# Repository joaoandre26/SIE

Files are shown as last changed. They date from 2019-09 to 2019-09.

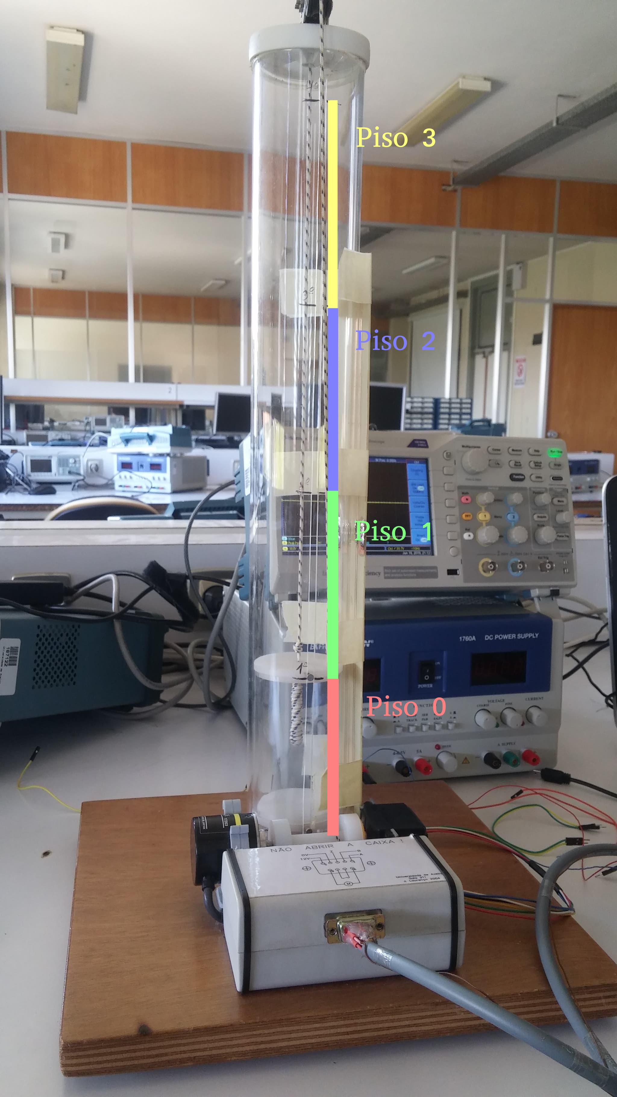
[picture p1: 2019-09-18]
Elevator_PCB/Imagens/prot_n.jpg

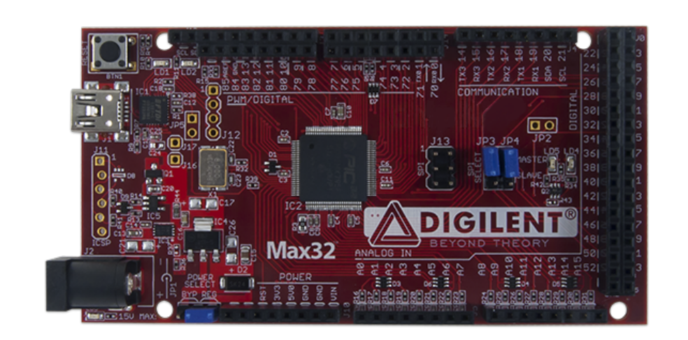
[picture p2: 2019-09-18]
Elevator_PCB/Imagens/mmicro.png

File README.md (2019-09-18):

# SIE
Trabalho desenvolvido no âmbito da UC de Sistemas de Instrumentação em Eletrónica, 4º ano MIEET, ano lectivo 2018/19
Para esclarecer alguma dúvida relativamente ao trabalho desenvolvido na UC poderá contactar um dos membros do grupo por e-mail.

/*Examples*/
Na pasta MicrocontrollerExemple-master encontra-se codigo para o qual me baseei para escrever as funções do LCD. Muito Obrigado ao desenvolvedor, foi uma grande ajuda.
Link: https://github.com/andrade824/Microcontroller-Example-Code

/*Info/Reports*/
Na pasta reports encontra-se os relatorios de todas as fases deste projecto, bem como o manual de utilizador. Deverá encontrar no manual do utilizador todas as intruções para colocar o nosso projecto em total funcionamento.

/*Elevator_PCB*/
Na pasta elevatorpcb encontra-se os gerber files para imprimir o nosso pcb, e os esquemas de montagem por nós utilizados.

/*Code*/
Na pasta Elevator_Code encontra o codigo referente ao projecto 0, assim como a versão final funcional de codigo para colocar no elevador. Existem alguns erros no codigo que poderão virificar em detalhe no report da fase 3.

Notas:
O trabalho desenvolvido que se encontra neste repositório está completamente funcional, não contemplando todas as especificações exigidas inicialmente, é o suficiente para colocar o elevador a subir e descer para qualquer um dos andares.

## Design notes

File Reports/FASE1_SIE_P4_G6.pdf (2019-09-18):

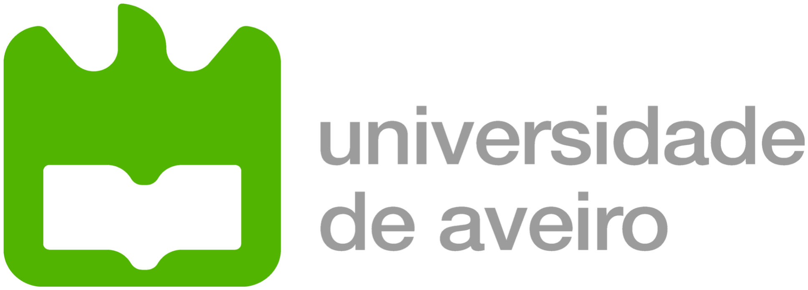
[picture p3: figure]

## Departamento de electrónica, telecomunicações e informática

Curso | 8204 - Mestrado Integrado em Engenharia Electrónica e Telecomunicações
Disciplina | 41489 - Sistemas de Instrumentação Eletrónica

## Ano Lectivo 2018/2019

# Primeira Fase

# Trabalho 4 - Controlo de Velocidade e Posição de um Elevador

## Autores:

76517 | João André de Jesus Cruz
76674 | Henrique da Silva Bernardes Camello Martins
Turma | P4
Grupo | G6
Data | 12 de Março de 2019
Docente | Pedro Fonseca

Primeira Fase - Controlo de Velocidade e Posição de um Elevador

## Índice

1 Introdução | 2
2 Objetivos | 2
3 Especificações do Projeto | 2
4 Diagramas de Blocos | 2
5 Esquema Elétrico | 5
6 Diagrama de rede - PERT | 7
7 Conclusão | 11
8 Bibliografia | 11

## 1 Introdução

Este projeto a ser realizado no contexto das aulas práticas de Sistemas de Instrumentação Eletrónica, tem como objetivo, o controlo da posição e velocidade de um elevador. Para isso, irá se desenvolver-se um sistema baseado num microcontrolador sendo este mesmo o Max32 Digilent.
Quanto ao funcionamento do elevador, resumidamente este está acoplado a um sistema cabo roldana, que está ligado a um motor e que tem o seu veio ligado a um codificador incremental bi-fásico.
A velocidade e posição do elevador, será controlada pelo microcontrolador e pelo PC. A escolha da posição será feita pelo utilizador, com recurso a uma consola. Quanto à velocidade, essa será controlada de acordo com um perfil calculado, a partir de parâmetros enviados por um PC.
Este relatório referente à primeira fase apresenta as especificações do projeto, a componente hardware, as variações e grandezas dos sinais em pontos críticos e por fim a estruturação das atividades a desenvolver.

## 2 Objetivos

Sabendo que o objetivo do projeto é o controlo e a velocidade de um elevador, este mesmo pode funcionar em duas direções diferentes (para baixo e cima), é usado um push-pull driver, que através de uma ponte H, faz com que o motor varie o sentido de rotação conforme o sinal PWN recebido.
O utilizador, como já referido na Introdução irá interagir com o sistema, podendo escolher a posição. A velocidade e a posição irá ser apresentada num display LCD.
Nesta primeira fase, tem-se como objetivos apresentar o diagrama de blocos, esquemas elétricos com o hardware detalhado, identificação dos sinais e gamas de variação, em pontos de interesse dos circuitos e no fim um diagrama PERT com a distribuição do esforço, dependências e a calendarização.

## 3 Especificações do Projeto

- Definição do ponto de chegada em coordenadas do encoder.
- Capacidade de programação dos parâmetros Vmax, Vapr e Dapr com configuração automática dos perfis
- Capacidade de alimentação de motor DC (5V / 1W).
- Encoder bi-fásico com saída TTL e 500 ipr
- Deteção de piso por sensor de proximidade (efeito de hall), com auto-calibração
- Adicionalmente: capacidade de programação dos parâmetros do controlador.
- Medição da corrente consumida.

## 4 Diagramas de Blocos

Recorrendo ao diagrama apresentado no guião dos trabalhos práticos, concluímos que como entradas temos: a posição dada pelo encoder, os quatro sensores por andar, o sensor do piso zero e o andar desejado pelo utilizador. Como saídas, temos: o controlo do motor e um display LCD para apresentar a velocidade e posição do elevador.
Posto isto, fez-se o desenho dos diagramas de blocos do nível zero ao nível dois.

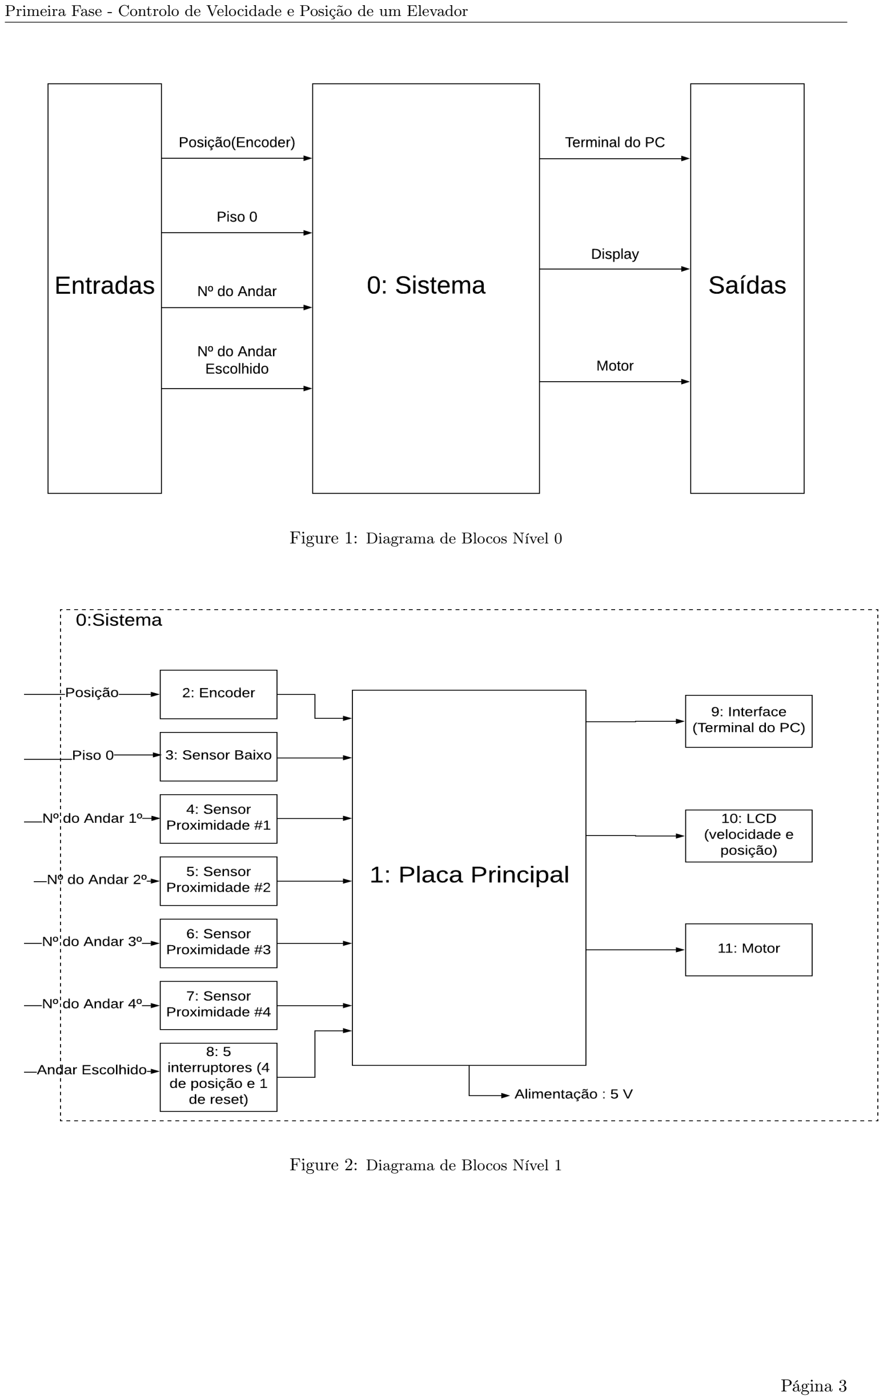
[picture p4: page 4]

Figure 1: Diagrama de Blocos Nível 0

Figure 2: Diagrama de Blocos Nível 1

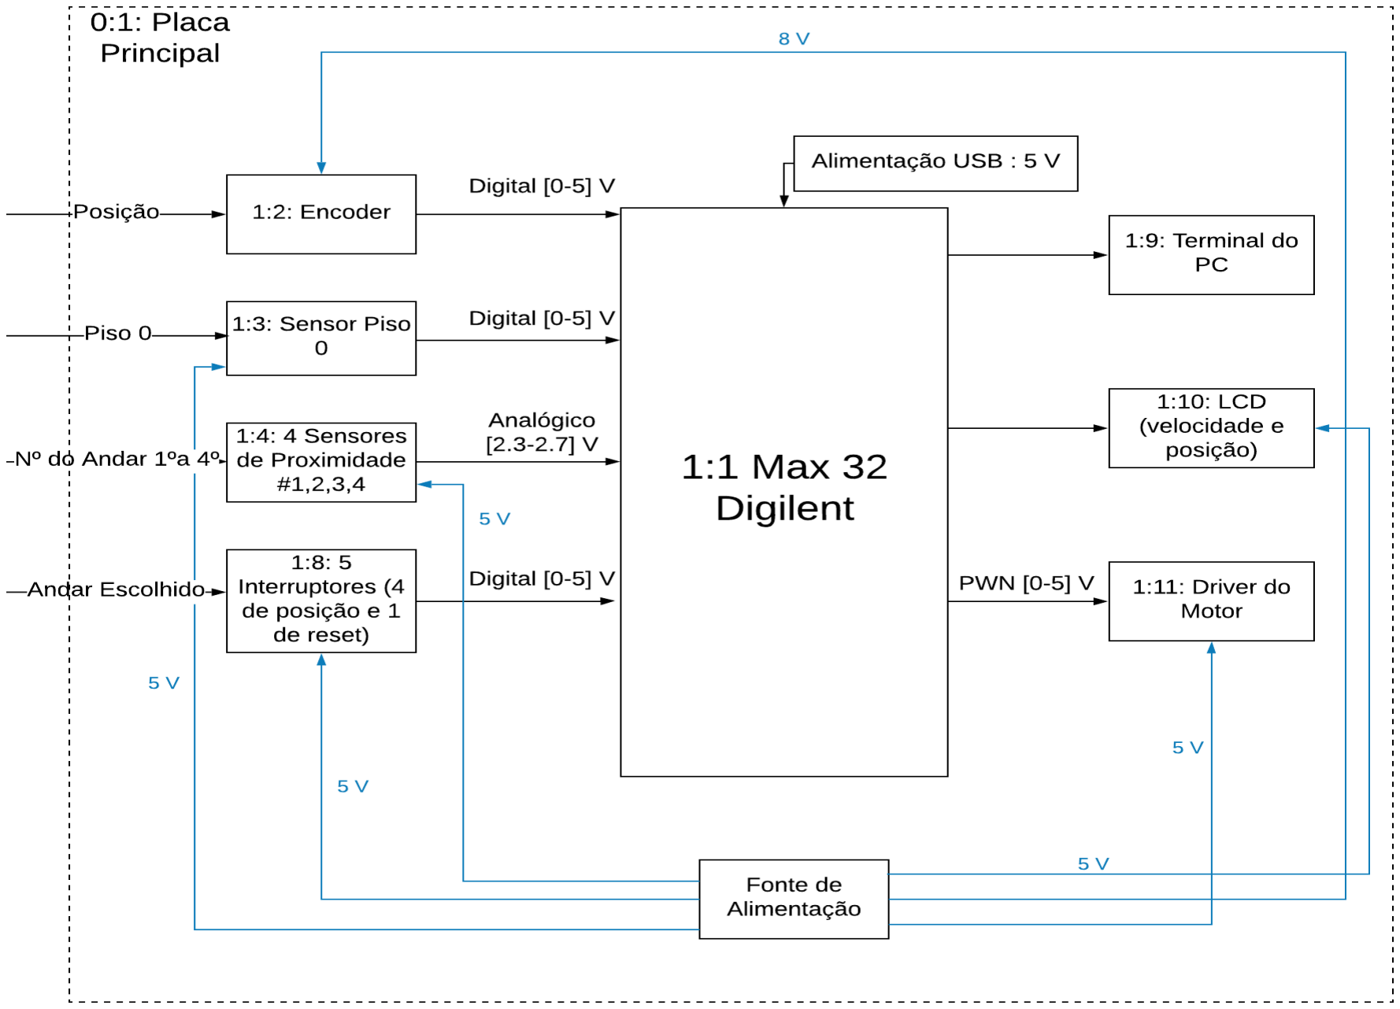
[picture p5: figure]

Figure 3: Diagrama de Blocos Nível 2

## 5 Esquema Elétrico

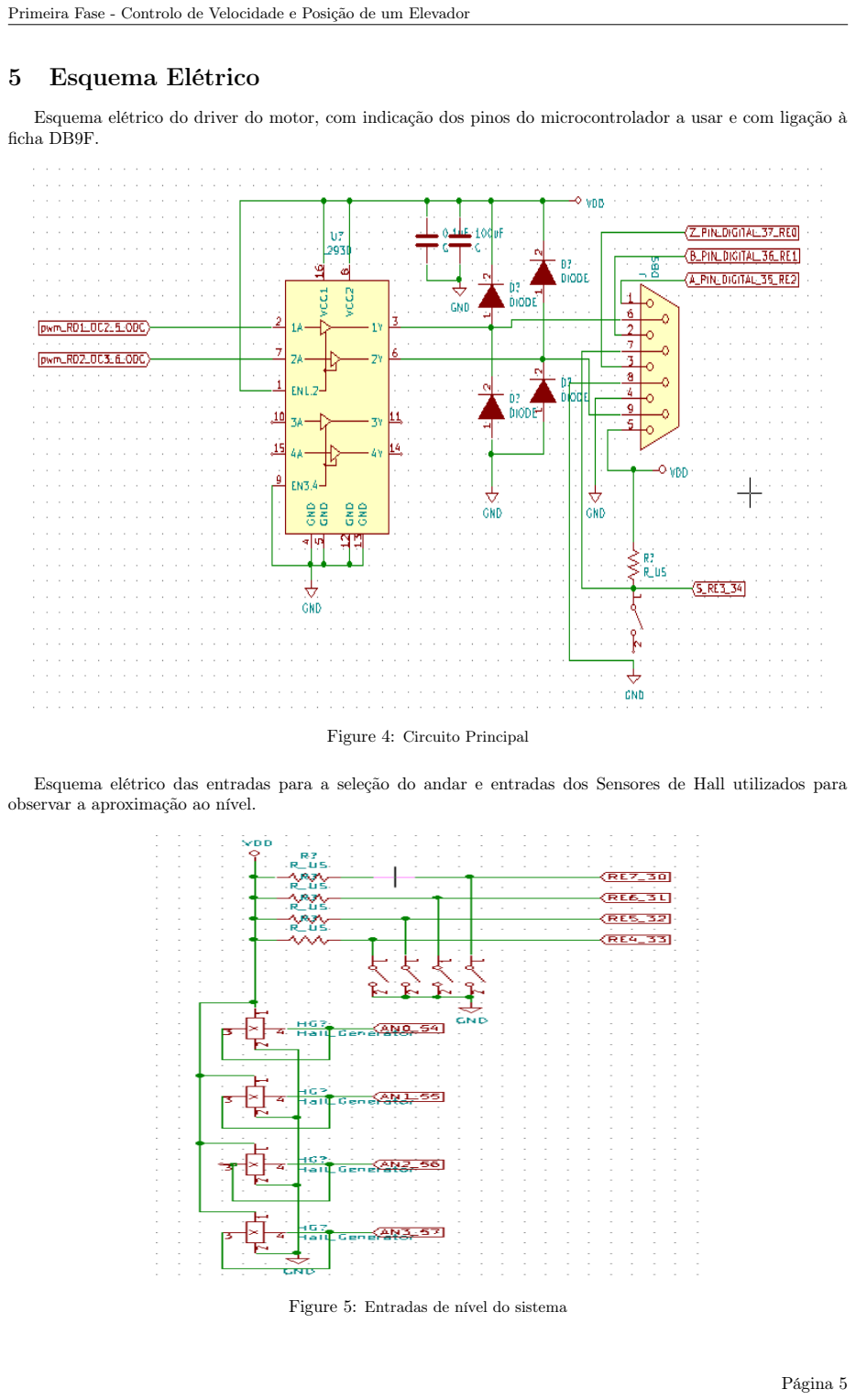
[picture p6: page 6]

Esquema elétrico do driver do motor, com indicação dos pinos do microcontrolador a usar e com ligação à ficha DB9F.

Figure 4: Circuito Principal

Esquema elétrico das entradas para a seleção do andar e entradas dos Sensores de Hall utilizados para observar a aproximação ao nível.

Figure 5: Entradas de nível do sistema

Esquema elétrico para o display da velocidade e da posição onde o elevador se encontra.

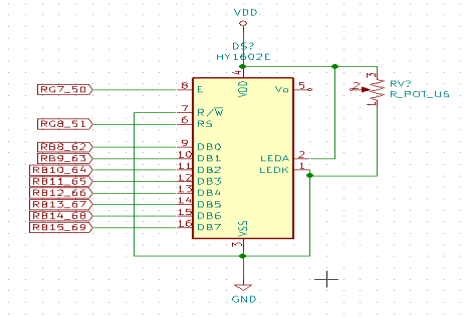
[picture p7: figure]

Figure 6: Display de resultados

## 6 Diagrama de rede - PERT

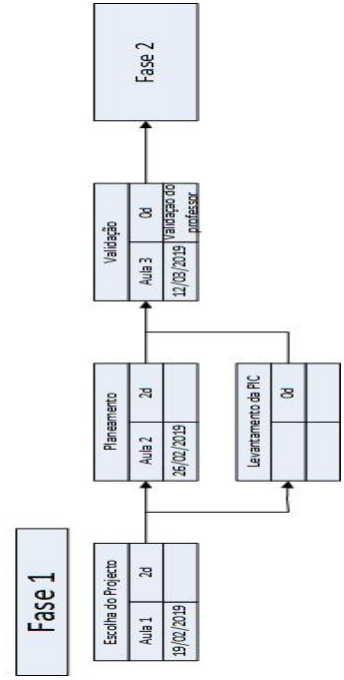
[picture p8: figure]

Figure 7: Diagrama Fase 1

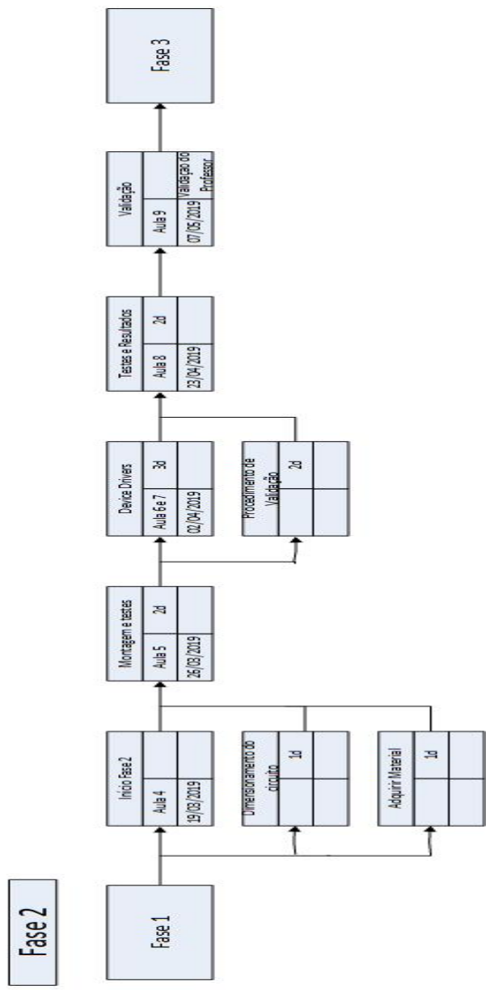
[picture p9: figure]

Figure 8: Diagrama Fase 2

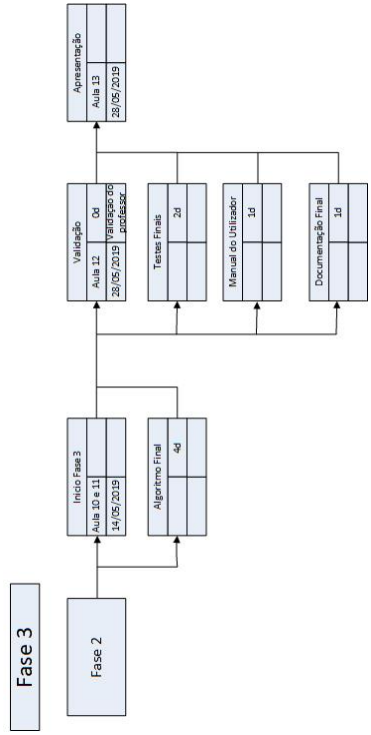
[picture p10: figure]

Figure 9: Diagrama Fase 3

1 dia = 8h de trabalho

Tabela de atividade

Atividade | Precedente | Tempo | Aula
A - Escolha | | 0d | 1
B - Planeamento | A | 2d | 2
C - Levantamento da pic | A | 0d | 2
D - Validação | B, C | 0d | 3
E - Início fase 2 | D | 0d | 4
F - Dimensionamento do circuito | D | 2d | 4
G - Adquirir Material | D | 1d | 4
H - Montagem e testes | E, F, G | 2d | 5
I - Device Drivers | H | 3d | 6 e 7
J - Procedimento de Validação | H | 2d | 6 e 7
K - Testes e Resultados | I, J | 2d | 8
L - Validação | K | 0d | 9
M - Início fase 3 | L | 0d | 10 e 11
N - Algoritmo final | L | 4d | 10 e 11
O - Validação | M, N | 0d | 12
P - Testes finais | M, N | 2d | 12
Q - Manual Utilizador | M, N | 1d | 12
R - Documentação final | M, N | 1d | 12
S - Apresentação | O, P, Q, R | 0d | 13

## 7 Conclusão

Quanto à primeira fase atingimos os objetivos impostos pelo guião da disciplina, sendo estes a apresentação dos diagramas de blocos, esquema elétrico detalhado do hardware, listagem dos tipos de sinais e gamas de variação em pontos críticos e no fim o diagrama de PERT com o planeamento do projeto.
No futuro podem haver alterações no que foi apresentado nesta fase inicial. Pois na fase seguinte, procede-se à montagem do hardware,desenvolvimento do software base e validação. As possíveis alterações serão apresen-tadas, em versões atualizadas no relatório da segunda fase.

## 8 Bibliografia

Apontamentos de Sistemas de Instrumentação Eletrónica, fornecidos pelo docente.

Esquema do Elevador,
https://elearning.ua.pt/pluginfile.php/962673/mod_resource/content/1/praticas/trabalhos/t4/elevador. pdf (https://elearning.ua.pt/pluginfile.php/962673/mod_resource/content/1/praticas/trabalhos/t4/elevador.pdf)
OMRON ,Rotary Encoder E6B2 Datasheet, https://elearning.ua.pt/pluginfile.php/962676/mod_resource/content/1/praticas/trabalhos/t4/omrom_e6b2.pdf (https://elearning.ua.pt/pluginfile.php/962676/mod_resource/content/1/praticas/trabalhos/t4/omrom_e6b2.pdf)
SGS-THOMSON MICROELECTRONICS, l293B,L293E, Datasheet, https://elearning.ua.pt/pluginfile.php/962679/mod_resource/content/1/praticas/trabalhos/t4/l293. pdf (https://elearning.ua.pt/pluginfile.php/962679/mod_resource/content/1/praticas/trabalhos/t4/l293.pdf)
HONEYWELL,SS495A-S,Datasheet https://sensing.honeywell.com/honeywell-sensing-sensors-linear-hall-effect-ics-ss490-series-\ datasheet-005843-2-en.pdf
Manual de referência online da Max32 Digilent, https://elearning.ua.pt/pluginfile.php/963675/mod_resource/content/1/chipkit-max32_rm.pdf

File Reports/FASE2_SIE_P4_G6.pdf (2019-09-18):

## Departamento de electrónica, telecomunicações e informática

Curso | 8204 - Mestrado Integrado em Engenharia Electrónica e Telecomunicações
Disciplina | 41489 - Sistemas de Instrumentação Eletrónica

## Ano Lectivo 2018/2019

# Segunda Fase

# Trabalho 4 - Controlo de Velocidade e Posição de um Elevador

## Autores:

76517 | João André de Jesus Cruz
76674 | Henrique da Silva Bernardes Camello Martins
Turma | P4
Grupo | G6
Data | 7 de Maio de 2019
Docente | Pedro Fonseca

Segunda Fase - Controlo de Velocidade e Posição de um Elevador

## Índice

1 Introdução | 2
2 Objetivos | 2
3 Especificações do Projeto | 2
4 Descrição do Hardware | 3
5 Arquitetura de Software | 9
6 Testes e Resultados | 14
7 Memória Descritiva | 27
8 Conclusão | 28
9 Bibliografia | 28

## 1 Introdução

Este projeto a ser realizado no contexto das aulas práticas de Sistemas de Instrumentação Eletrónica, tem como objetivo, o controlo da posição e velocidade de um elevador. Para isso, irá se desenvolver-se um sistema baseado num microcontrolador sendo este mesmo o Max32 Digilent.
Quanto ao funcionamento do elevador, resumidamente este está acoplado a um sistema cabo roldana, que está ligado a um motor e que tem o seu veio ligado a um codificador incremental bi-fásico.
A velocidade e posição do elevador, será controlada pelo microcontrolador e pelo PC. A escolha da posição será feita pelo utilizador, com recurso a uma consola. Quanto à velocidade, essa será controlada de acordo com um perfil calculado, a partir de parâmetros enviados por um PC.
Este relatório referente à segunda fase apresenta as especificações dos procedimentos de validação e várias tabelas com os resultados dos testes efetuados. É importante referir que no fim da segunda fase todos os componentes estão montados e o software base está desenvolvido.

## 2 Objetivos

Sabendo que o objetivo do projeto é o controlo e a velocidade de um elevador, este mesmo pode funcionar em duas direções diferentes (para baixo e cima), é usada uma ponte H que faz com que o motor varie o sentido de rotação conforme o sinal PWN recebido.
O utilizador, como já referido na Introdução irá interagir com o sistema, podendo escolher a posição. A velocidade e a posição irá ser apresentada num display LCD.
Na segunda fase, tem-se como objetivos a apresentação das especificações dos procedimentos de validação, várias tabelas com os resultados dos testes efetuados, todos os componentes devidamente montados e o software base desenvolvido.

## 3 Especificações do Projeto

- Definição do ponto de chegada em coordenadas do encoder.
- Capacidade de programação dos parâmetros Vmax, Vapr e Dapr com configuração automática dos perfis
- Capacidade de alimentação de motor DC (5V / 1W).
- Encoder bi-fásico com saída TTL e 500 ipr
- Deteção de piso por sensor de proximidade (efeito de hall), com auto-calibração
- Adicionalmente: capacidade de programação dos parâmetros do controlador.
- Medição da corrente consumida.

## 4 Descrição do Hardware

### 4.1 Driver do Motor

Para o driver do motor utilizou-se o integrado L293NE. Após a análise do datasheet do componente e da investigação do funcionamento de uma Ponte H chegámos às seguintes conclusões.
O L293 é controlado por um sinal PWM, que terá de ter uma tensão mínima de alimentação e lógica de cerca de 4.5 V. Posto isto, recorremos às saídas open drain do micro controlador que permitem a geração de sinais até 5 V, o que cumpre com os mínimos de tensão anteriormente apresentados. A alimentação do componente, é feita através da fonte de alimentação da bancada da sala de aula.
Quanto ao funcionamento da ponte H este é um circuito que contém normalmente quatro transístores bipolares FETs que funcionam como switches. Cada um é controlado individualmente. Com Q1 e Q4 ativos há passagem de corrente pelo motor fazendo com que rode num sentido. Com Q3 e Q2 ativos o motor roda no sentido contrário. Os quatro transístores nunca podem estar os quatro ativos pois pode-se danificar o circuito. No caso do L293 já possui um mecanismo de proteção para este tipo de situação.
O controlo do L293 é feito com um sinal PWM que corresponde a um sinal periódico retangular com frequência constante em que o seu tempo ON (sinal a 1) pode ser variável. Para isso varia-se o duty cycle que equivale à relação do período do sinal e o período a ON (sinal a 1). Logicamente com a variação do duty cycle do sinal PWM consegue-se controlar, o tempo em que os transístores estão ativos, o que equivale a controlar a velocidade do motor. A expressão do duty cycle do sinal PWM é dado pela seguinte fórmula:

DutyCycle =

tON
T

∗ 100%

Já as conexões entre o motor e o driver são efetuadas através de uma ficha DBF9, que está no elevador, foi então necessário um cabo com uma ficha num dos lados e headers na outra, para fazer a ligação necessária. Tal como é visível no seguinte esquema:

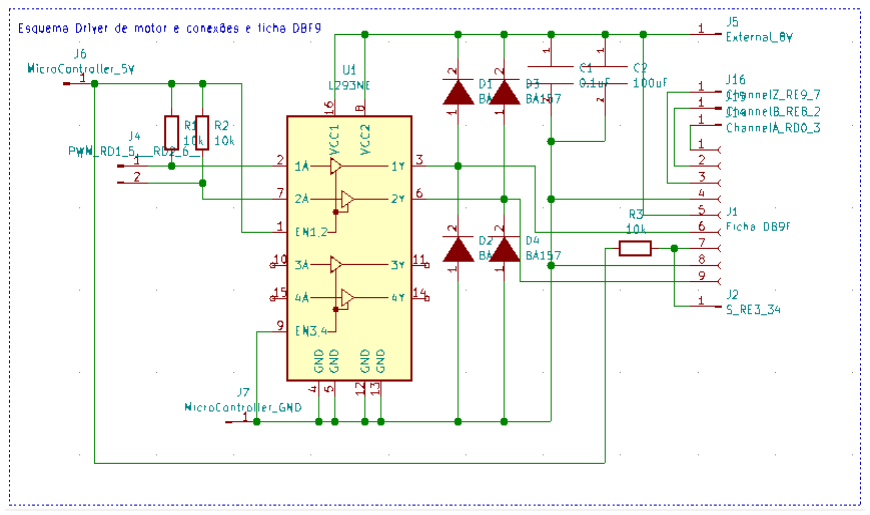
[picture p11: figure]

Figure 1: Esquema Elétrico do driver de motor

Os pinos utilizados nos quais obtemos um sinal PWM como saída, correspondem aos pinos 5 (RD1) e 6 (RD2) do Kit, o ground e a alimentação, que contém uma resistência de pull-up para cada uma das saídas de PWM, para que o open drain funcione.

### 4.2 Interface com o utilizador

### 4.3 Display LCD

Para a apresentação da posição e da velocidade do elevador escolheu-se usar um display LCD.
O display LCD tem como pinos: o display de contraste (V0), pinos de alimnetação (5V e GND), 8 pinos de dados (D0-D7), um pino do modo de leitura ou escrita (R/W), um pino de enable para autorizar a escrita nos registos e por fim um pino da escolha do registo(RS) que controla onde se escreve na memória do LCD ou enviar comandos.
O display LCD pode ser controlado por dois modos de 4 bits e de 8 bits. O de 4 bits requer o uso de sete pinos do microcontrolador e o de 8 bits o uso de 11 pinos.
Na figura seguinte apresenta-se o esquema elétrico com as ligações do display LCD.

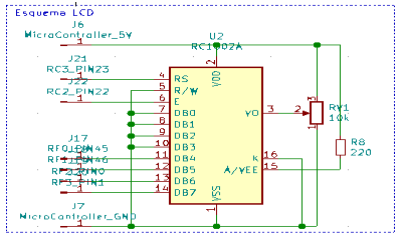
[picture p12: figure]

Figure 2: Esquema Elétrico do LCD

Para ligar o LCD à PIC utilizamos o modo de 4 bits e os pinos RS e E, não é necessário ligar o pino R/W uma vez que apenas se vão efectuar operações de escrita, assim este pino so precisa de ser ligado à massa. Os 4 pinos de dados (DB4-DB7) foram ligados aos pinos 45 (RF0), 46 (RF1), 0 (RF2) e 25 (RF3), já o pino enable ao 22 (RC2) e o pino RS ao 23 (RC3).

### 4.4 Botões

Para o controlo da posição do elevador utilizaram-se quatros botões, um para cada piso.
Na figura seguinte apresenta-se um esquema sintético de um push button, quando o botão é acionado cria-se uma ligação entres os pinos de cada lado (BC e AD) onde neste caso ocorre passagem de corrente.

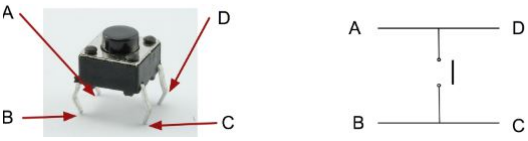
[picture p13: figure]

Figure 3: Esquema Elétrico de um push button

Quando à montagem dos botões recorreu-se a uma tensão de alimentação de 5 V (5 V do porto do microcontrolador),conectou-se uma resistência de pull up de cerca de 10kΩ em série com o botão (uma em cada botão) e por fim liga-se um pino do microcontrolador entre a resistência e o botão para assim fazer-se a sua leitura. Posto isto, a resistência liga-se ao pino B do botão e o pino D liga-se à massa. Na figura seguinte apresenta-se as ligações feitas dos quatro botões.
Pretende-se que o botão apresente apenas dois estados High(5 V) e Low (0 V) para isso é que se usou a resistência pull up com o objetivo que o valor não varie. Quando o botão não está premido, o circuito está em aberto fazendo com que a queda de tensão na resistência seja nula, logo o valor de tensão lido pelo microcontrolador é de 5 V equivalente ao estado High, mais tarde negado pelo software. No caso de estar premido, o circuito encontra-se fechado logo ocorre passagem de corrente no botão e por consequência a queda de tensão na resistência é de cerca de 5 V. Portanto o valor de tensão lido pelo microcontrolador é de 0 V equivalente ao estado Low, sendo que mais tarde é negado pelo software. Assim o microcontrolador consegue fazer uma leitura correta do estado do botão em causa e concluir se o botão está premido ou não.
Tal como já está descrito acima a forma como os push butons funcionam, mostra-se na figura seguinte como se conectam ao microcontrolador.

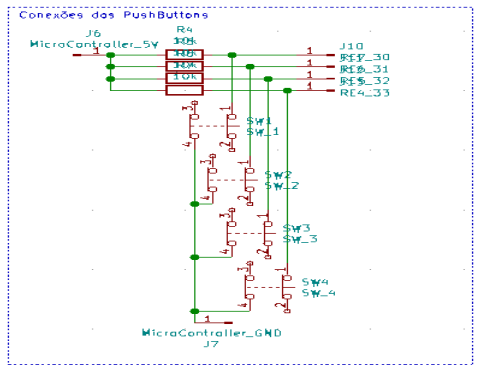
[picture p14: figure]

Figure 4: Esquema Elétrico dos PushButtons

Como é visível no esquema eléctrico os quatro botões encontram-se ligados aos pinos 30 (RE7), 31 (RE6), 32 (RE5) e 33 (RE4), enquanto o botão do piso zero se encontra ligado ao pino 34(RE3).

### 4.5 Encoder

Neste projeto usa-se um encoder incremental que produz 500 impulsos por revolução e tem três canais A,B e Z. O modelo usado neste projeto é o E6B2-CWZ6C da OMRON.
O encoder tem dois sentidos de rotação, sentido horário ou anti-horário. Analisando o sentido horário, a fase A irá estar adiantada 90º em relação à fase B. Comparando diretamente a fase A e B e observando atentamente o nível das duas fases, chega-se à conclusão que neste caso (sentido horário) o nível da fase A é diferente do da fase B. Logo quando há uma mudança do nível da fase A o nível da fase B contraria o nível do da A. Este fenómeno é evidenciado na figura seguinte.
No sentido anti-horário a fase A encontra-se atrasada 90º em relação à fase B. Quanto ao nível das fases, neste caso, encontram-se sempre iguais. Este fenómeno é evidenciado na figura seguinte. Portanto através da leitura e análise das fases do encoder, consegue-se afirmar qual o sentido de rotação deste mesmo, recorrendo a um algoritmo simples de controlo por software. Este baseia-se na observação do nível das fases, quando o nível do canal B é diferente do A incrementa-se a posição pois o encoder roda no sentido horário. Com os níveis dos dois canais diferentes a posição decrementa-se pois roda no sentido anti-horário.

(a) Fases A,B e Z | (b) Níveis das fases A,B e Z

Figure 5: Sentido horário

(a) Fases A,B e Z | (b) Níveis das fases A,B e Z

Figure 6: Sentido anti-horário

Quanto à implementação, sabe-se que a porta DB9F tem os três canais e que cada um é um sinal TTL de 5V. Logo pode-se ligar diretamente as fases ao microcontrolador, pois os pinos deste mesmo são tolerantes a 5V. A leitura dos níveis dos três canais é feito com interrupções externas que detetam mudanças de nível, sabendo que apenas alguns dos pinos são tolerantes a interrupções deste género, selecionaram-se as interrupções 0, 1 e 2, que correspondem aos pinos 3(RD0), 2(RE8) e 7(RE9) para as fases A, B e Z,respetivamente. O método implementado está mais à frente aprofundado na secção Arquitetura de Software.
Quanto à alimentação do encoder, de acordo com o seu datasheet, é cerca de 5 V. Aplica-se uma tensão à fonte de alimentação do elevador, que por sua vez alimenta o elevador mais o encoder. Este regulador é o tipo 7805 que pelo seu datasheet necessita no mínimo 7V de tensão de alimentação para funcionar corretamente. E ainda existe um díodo que apresenta uma queda de tensão, logo considerando todos estes fatores mais o conselho por parte do docente, a alimentação irá ser de 8V.

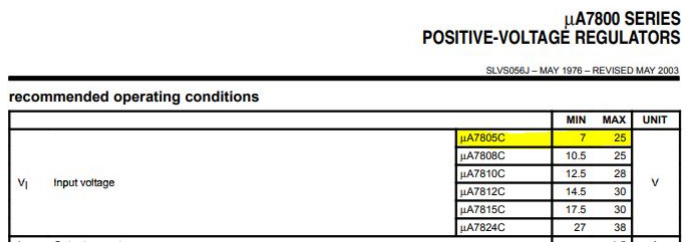
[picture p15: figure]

Figure 7: Extrato do Datasheet do LM7085

### 4.6 Sensor de Efeito de Hall

O efeito de Hall por definição é: o aparecimento de uma diferença de potencial em um condutor elétrico, transversal ao fluxo de corrente e um campo magnético perpendicular à corrente.
Os Sensores de efeito de Hall são ativados por um campo magnético exterior, logo o sinal de saída é em função da densidade do campo magnético na proximidade do sensor. O campo magnético tem dois aspetos a densidade de fluxo magnético (B) e a sua polaridade (Norte ou Sul). No caso do sensor ser linear e for analógico, a sua tensão de saída é dada pela equação seguinte:

Vth = Rth ∗ (

I
t

∗ B)

Em que Vth é a tensão de Hall, Rth é o coeficiente de Hall, I é a corrente que atravessa o sensor, t é a espessura do sensor em (mm) e B é o fluxo magnético em Tesla. A resposta típica de um sensor de Hall a um campo magnético é dado pelo seguinte gráfico. Conclui-se que a tensão de saída do sensor aumenta com o aumento do campo magnético, até que comece a saturar pelos limites impostos pela sua alimentação. Portanto vê-se que a tensão de saída é proporcional ao campo magnético.

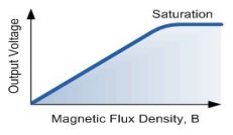
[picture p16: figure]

Figure 8: Gráfico V0/B num sensor de efeito de Hall

Quanto ao projeto em si, cada andar possui um sensor, obtendo no total quatro sensores de efeito de Hall de modelo SS495A da Honeywell. Após uma leitura e análise do datasheet do componente, conclui-se que para uma densidade do campo magnético de 0 B apresenta uma tensão de saída referencia de 2.5 V (Vdc). Com um campo magnético aplicado (de -670 B a 670 B tipicamente) obtêm-se variações típicas de 0.2 ∗ Vdc a Vs − (0.2 ∗ Vdc), também se sabe que a tensão de alimentação tem de ser no mínimo 4.5 V. Portanto sabendo que os pinos do microcontrolador conseguem produzir uma tensão de 5 V, os sensores são alimentados com ela e obtém-se uma variação entre 0.5 V e 4.5 V à saída de cada um. Este facto pode-se observar no gráfico seguinte do datasheet do componente.

(a) Gama da tensão de saída
(b) Gama da densidade do campo magnético
(c) Gráfico V0/B

Figure 9: Extratos do Datasheet do SS495A

A montagem dos sensores de Hall já se encontra feita no elevador logo, apenas é necessário fazer a leitura de cada sensor recorrendo ao microcontrolador e fazer a sua devia alimentação. Para se lerem os valores de tensão obtidos nos sensores é necessário utilizar uma ADC, em que a mesma seja uma porta analógica, neste caso em concreto usou-se as portas analógicas AN0, AN1, AN2 e AN3 que correspondem aos pinos 54(RB0) a 57(RB3). Mais à frente na secção dos testes, conclui-se que o sensor na presença de um campo magnético tem uma tensão de saída de cerca de 2.4V, com um tensão referencia de 2.5V.

Figure 10: Esquema da montagem dos sensores de efeito de Hall

## 5 Arquitetura de Software

Nesta secção do relatório da fase dois, são apresentados os device drivers e fluxogramas que ajudam a compreender o seu funcionamento.
Para a melhor organização, foi criado um ficheiro para cada módulo desenvolvido. Logo tem-se que :

PWM

LCD

ADC

Encoder

PushButtons

UART

É importante frisar que poderão ocorrer alterações dos device drivers na ultima fase do projeto mas na altura serão devidamente evidenciadas.

### 5.1 ConfigBits

Este módulo já nos é fornecido, tem como função a configuração do CLOCK e PBCLK, com os valores 80MHz e 40MHz, respetivamente.

### 5.2 PWM

Este módulo, junta todas as funções necessárias, para gerar dois sinais PWM com duty cycle variável e frequência de 20kHz. A figura seguinte resume o funcionamento do módulo desenvolvido.

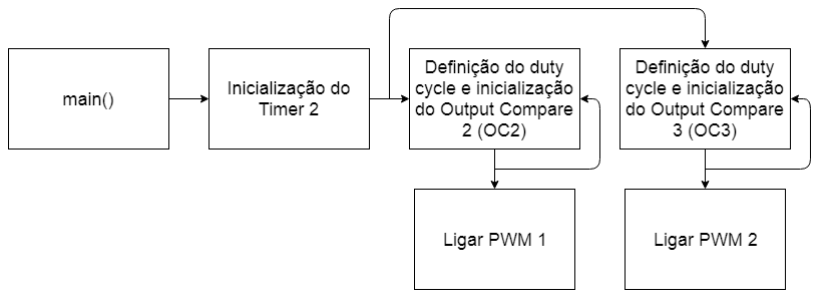
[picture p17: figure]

Figure 11: Diagrama de Fluxo da geração de duas PWM

A configuração deste módulo em específico foi facilitado pelo código já desenvolvido no projeto 0. Para a geração dos dois sinais PWM foi usado o Output Compare (OC2 e OC3) e para ambos o Timer 2 com uma frequência de cerca de 20kHz.
As funções desenvolvidas foram as seguintes:

SetTimer(void)

SetPWN1(dutyCycle)

SetPWN2(dutyCycle)

StartTimer(void)

A função SetTimer inicia os portos e configura o Timer 2 com uma frequência de 20 kHz. Para esse efeito usa-se a expressão enuncia a seguir para se obter o valor do PR2. Sendo o fin = 40MHz e o valor pretendido para a frequência fout = 20k o valor obtido para o PR2 é de 2000, com um valor de prescaler de 1.

fout =

fin
P Rx + 1

A função SetPWM1 e SetPWM2, são equivalentes sendo que, ambas têm como parâmetro de entrada o valor de duty cycle desejado pelo utilizador e cada uma produz um sinal PWM. A primeira recorre ao Output Compare 2 e a segunda ao Output Compare 3, ambas como já referido anteriormente usam o Timer 2. A partir do registo OC2RS e OC3RS respetivamente, é possível alterar os valores dos duty cycles dos sinais PWM’s gerados, de acordo com a seguinte formula:

OCxRs =

(P R2 + 1) ∗ δ
100

O sinal PWM proveniente do SetPWM1 é obtido no pino 5 e o do SetPWM2 no pino 6 da. Para além disto foram configuradas as saídas em open drain para que se consigam gerar sinais PWM com tensão máxima de 5V. Pois a ponte H necessita de tensões mínimas de 4.5 V, desta maneira evita-se o uso de hardware adicional, o que é uma vantagem. Apenas se usa um pull up resistor por cada saída.
Por fim a função StartTimer inicia a geração dos dois sinais PWM, configurando o registo T2CONbits.TON a 1.

### 5.3 LCD

Este módulo é responsável pelo display do da velocidade e o nível onde o elevador se encontra. A figura seguinte resume o funcionamento do módulo desenvolvido.

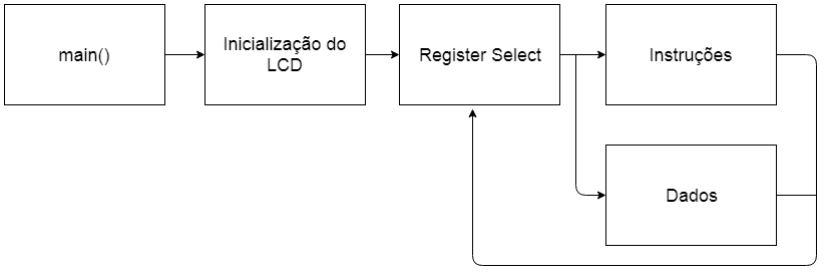
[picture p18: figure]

Figure 12: Diagrama de Fluxo da impressão de informação no LCD

Para a configuração e o display, o envio de comandos e caracteres, foram criadas as seguintes funções:

InitialiseDisplay(void)

ResetDisplay(void)

SendCommandToLCD(uint8_t uiCommand)

LCDSendString(char * str)

LCDSendChar(char character)

delay(uint32_t period)

A função mais importante deste módulo é a SendCommandToLCD, esta função é responsável por enviar comandos com as tarefas que o display deve executar, como Clear, Return Homne, Mode Set, Display ON/OFF, cursor Shift, etc. Estes comandos são responsáveis por muitos das tarefas que o display executa.
Depois da funçao anterior a função mais importante é InitialiseDisplay, esta função executa alguns dos comandos pela função anterior, que são responsáveis pelo iniciar do display, como o modo de funcionamento, 4/8bits ou 1/2 linhas, desligar o cursor, iniciar o Entry Mode seguindo-se pelo inicial do display. Entre cada um dos comandos é necessário um delay para que o comando seja executado, para isso existe também uma simples função que cria um delay, como parâmetro de entrada o valor de delay que se pretende em mS.
A função ResetDisplay executa por algumas vezes o Return Home.
Por fim as funções LCDSendString recebe um ponteiro de caracteres e envia um de cada vez para ser enviado para a função LCDSendChar, esta última envia os caracteres para o LCD.

### 5.4 ADC

Este módulo, junta todas as funções necessárias, para realizar a leitura da tensão dos quatro sensores de Hall. A figura seguinte resume o funcionamento do módulo desenvolvido.

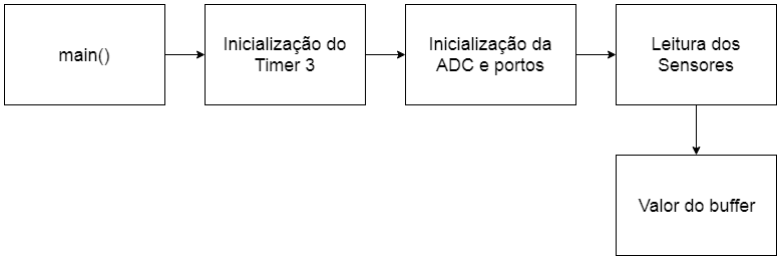
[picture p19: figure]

Figure 13: Diagrama de Fluxo da leitura dos sensores de Hall

As funções desenvolvidas foram as seguintes:

initADC(void)

initADCTimer(void)

readADCx(void)

buffer(void)

A primeira função deste módulo é initADC, esta função é responsável pelas configurações da ADC e a iniciação dos portos analógicos desta. São configurados os portos AN0 a AN3 como entradas.
A função initADCTimer serve para que seja feita uma leitura ao buffer com uma determinada frequência de amostragem sendo esta de cerca 400Hz. Para isso usou-se o Timer 3 com valores de prescaler e PR3, de 2 e 50000.
As funções readADCx, são 4 uma para cada sensor, cada uma seleciona o porto analógico devido a ler e fazem a decisão da comparência do elevador no andar em questão.
A função buffer é usada apenas para devolver o valor do buffer lido da ADC.

### 5.5 Encoder

Este módulo é responsável pela leitura dos três canais do encoder e pela decisão do sentido do movimento de elevador (para cima ou para baixo). A figura seguinte resume o funcionamento do módulo desenvolvido.

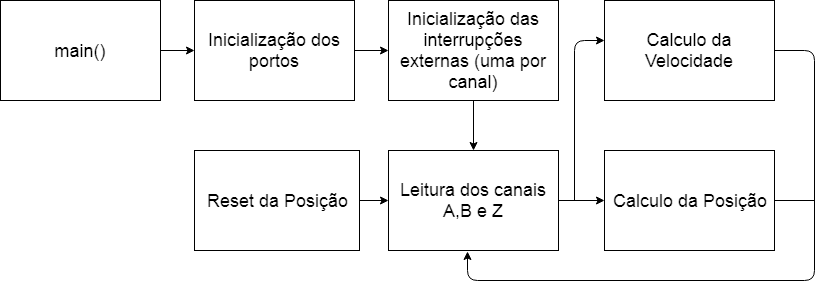
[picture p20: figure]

Figure 14: Diagrama de Fluxo da leitura dos canais A,B e Z, mais calculo de posição e velocidade

As funções implementadas neste módulo são as seguintes:

SetEncoderPorts(void)

SetExternalIntx(void)

GetChannelx(void)

GetPos(void)

ResetPos(void)

Init_Timerx_Interrupt()

A função SetEncoderPorts, serve para definir os portos de entrada responsáveis pela leitura do estado dos canais do encoder (Canal A,B e Z)
A SetExternalIntx inicia as interrupções externas para cada um dos canais A,B e Z do encoder.
A GetChannelx é responsável pela leitura do estado dos canais.
A função GetPos e ResetPos são responsáveis por devolver a posição do encoder e colocar o mesmo valor a zero.
Já a última função Init_Timerx_Interrupt, inicia dois timers por interrupções, cada um deles responsável pelo update da posição e o outro por calcular a velocidade. Tem-se o Timer 4 com uma frequência de 50Hz sendo este responsável pela obtenção da posição do elevador e o Timer 1 com uma frequência de 400Hz para o calculo da velocidade. O calculo da posição é feito por um método muito usado por software. Este algoritmo compara o estado dos canais A e B, se forem diferentes incrementa-se o contador da posição e forem iguais decrementa-se. O da velocidade faz-se a amostragem com uma frequência de 400Hz e dentro desse espaço de tempo vê-se a variação da posição do elevador. No fim divide-se a variação de posição pelo periodo de amostragem.
Sendo o objetivo deste módulo a leitura dos três canais do encoder, as funções SetExternalIntx estão configuradas para serem ativas numa raising edge do porto e no momento em que corre a interrupção lê-se o estado do canal e inverte-se o seu funcionamento para failing edge. Isto é possível graças ao registo INTCONbits.INTxEP. Logo com este principio de funcionamento o microcontrolador consegue ler com sucesso os três canais do encoder.

### 5.6 PushButtons

Este módulo é responsável pela leitura do estado dos quatro botões e do bottom switch instalado no elevador. A figura seguinte resume o funcionamento do módulo desenvolvido.

Figure 15: Diagrama de Fluxo da leitura dos botões e do bottom switch

Para isso criaram-se as seguintes funções:

InitButtons(void)

PushButtonx(void)

BottomSwitch(void)

A função InitButtons é responsável pela configuração das portas RE3 a RE7 como entradas.
Já as funções PushButtonx são as responsáveis por retornar o estado dos botões, 1 a 4 e do bottom switch. Estes mesmos estão ligados às porta RE3 a RE7.

### 5.7 UART

Este modulo surge da necessidade do sistema comunicar com o utilizador. A figura seguinte resume o funcionamento do módulo desenvolvido.

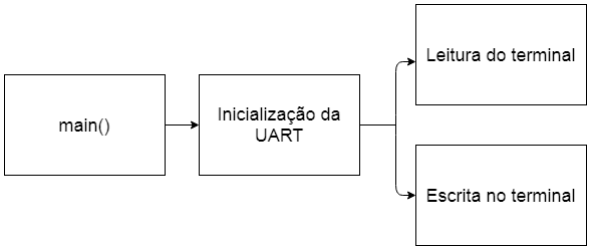
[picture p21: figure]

Figure 16: Diagrama de Fluxo da utilização da UART

Para tal foram usadas as funções seguintes:

InitUART(void)

PutChar(char r)

PutString(char *str)

GetChar(void)

A primeira função, InitUART, é responsável pela configuração da UART. Para isso é necessário definir a baudrate por forma a calcular o Baud Rate Register, por fim é necessário apenas iniciar a transmissão e a recepção. Para calcular o valor do registo mencionado utiliza-se a seguinte expressão:

UxBRG =

P BCLK + 8 ∗ baudrate
1616 ∗ baudrate − 1

As restantes funções PutChar, PutString e GetChar, estas são responsáveis pelo envio e receção de caracteres na uart. A primeira pela escrita do caracter como argumento, a segunda pela escrita de uma string no formato de array de caracteres e a terceira para a leitura de caracteres do terminal.

## 6 Testes e Resultados

### 6.1 Testes da geração dos sinais PWM

Objetivo:

Este teste tem como objetivo verificar a geração de dois sinais PWM, com tensão pico a pico de 5V, para um dado valor de duty cycle com uma frequência de 20 KHz.

Descrição e Resultados Esperados:

Tendo em conta que a ponte H, necessita de uma tensão mínima de 4.5 V, as saídas da Max32 Digilent têm de estar configuradas em open drain, pois com esta configuração consegue-se gerar sinais PWM de 5 V. Apenas se tem de adicionar um pull up resistor ao pino de saída.
Utilizando as funções StartTimer, SetPWM1 e SetPWM2, gerou-se na PWM1 um sinal com duty cycle de 50 % e na PWN2 com 30 %.
É expectável observar dois sinais PWM com os duty cycles referidos anteriormente e com uma tensão pico a pico de cerca de 5V.

Resultados:

Recorrendo ao osciloscópio da bancada mediram-se os dois sinais PWM gerados, tendo obtido as três figuras seguintes. Na primeira têm-se o sinal PMW1 com duty cycle de 50 %, na segunda a PWM2 com dutycycle de 30 e por fim os dois sinais juntos.

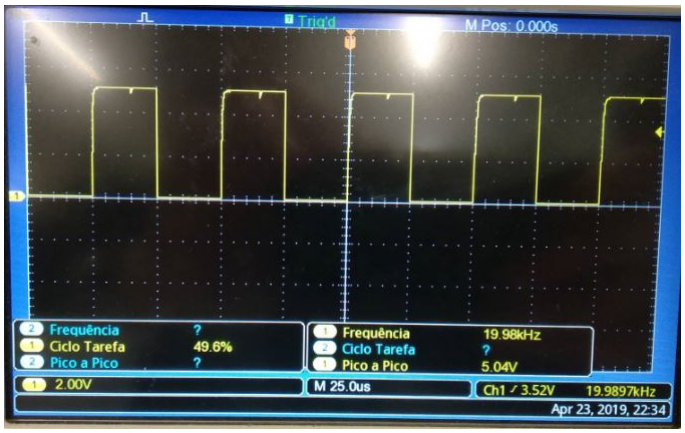
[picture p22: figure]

Figure 17: PWN 1 com δ = 50%

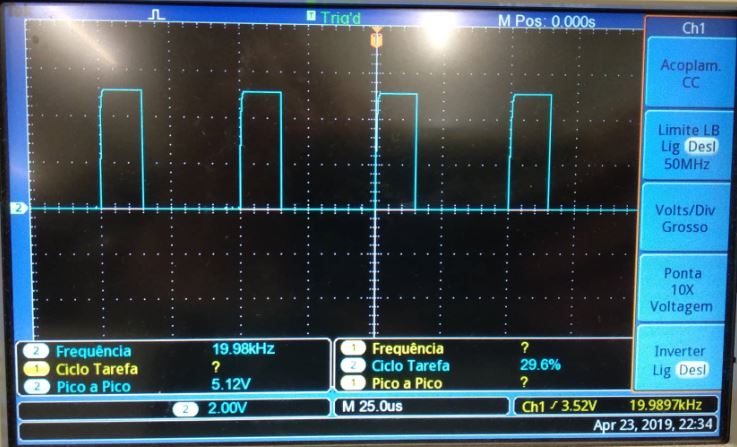
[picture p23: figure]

Figure 18: PWN 2 com δ = 30%

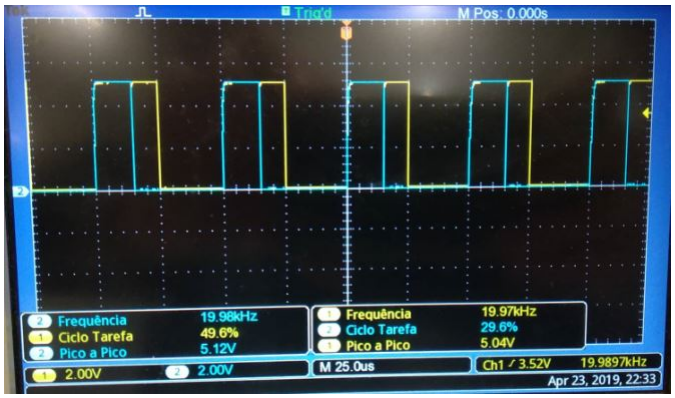
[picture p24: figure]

Figure 19: PWM 1 com δ = 50% e PWM 2 com δ = 30%

Análise:

Os valores de duty cycle obtidos vão de encontro com o esperado. Quanto à frequência de ambas é cerca de 20kHZ e tensão máxima de 5 V como esperado. Portanto conclui-se que os resultados obtidos vão de encontro ao expetável e estão corretos. Sendo que este módulo é capaz de produzir dois sinais PWM à escolha, com qualquer valor de duty cycle e frequencia de 20kHz.

### 6.2 Testes dos sinais obtidos na ponte H e movimento do elevador

Objetivo:

Verificação do bom funcionamento da ponte H e observação do movimento do elevador.

Descrição e Resultados Esperados:

Com vista em testar a ponte H, foi montada de acordo com o já explicado na secção Arquitetura de Software
- Driver do Motor.

Utilizando as funções StartTimer, SetPWM1 e SetPWM2 geraram-se dois sinais PWM para várias combinações de duty cycles. Os pares de valores foram 70% e 0% , 0% e 70%, 100% e 0%, 0% e 100% e por fim 50% e 50%.
Quanto aos resultados expectáveis, no primeiro par de valores um sinal PWM com visto anteriormente em Testes da geração dos sinais PWM - Resultados para o PWM 1 e no PWM2 uma tensão de cerca de 0V. No segundo par de valores o inverso da situação anterior, no terceiro na PWM1 uma tensão constante de 5V e na PWM2 uma tensão de cerca de 0V, no quarto o inverso dos resultados na terceira e por ultimo dois sinais PWM exatamente iguais.
Quanto ao movimento do elevador se o duty cycle da PWM1 é maior que a PWM2 o elevador desce, inversamente se o duty cycle da PWM2 for maior que o da PWM1 o elevador sobe. No caso em que os sinais são iguais o elevador prevê-se não possuir qualquer movimento. Também se prevê que quanto maior o dutycyle da função mais rápido será o deslocamento do elevador, pois maior é o tempo em que o sinal se encontra a ON.

Resultados:

Utilizando as funções já enunciadas na secção Testes e Resultados - Testes de geração dos sinais PWM e usando vários valores de duty cycle para cada um dos sinais PWM, estes dois sinais foram conectados às entradas na Ponte H. Logo utilizando o osciloscópio da bancada, as saídas da ponte H foram as seguintes:

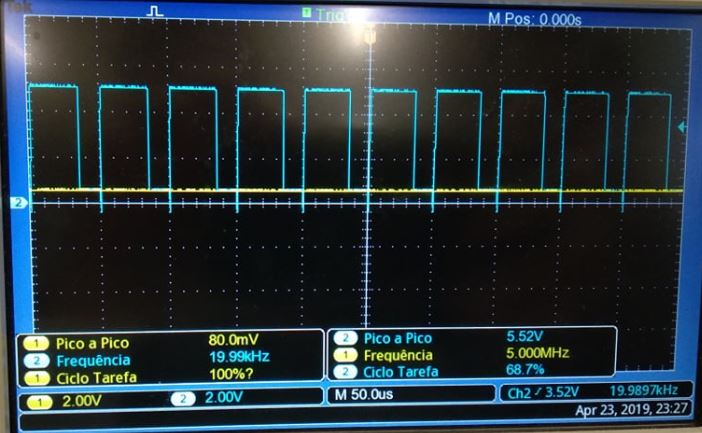
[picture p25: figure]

Figure 20: PWM 1 com δ = 70% e PWM 2 com δ = 0%

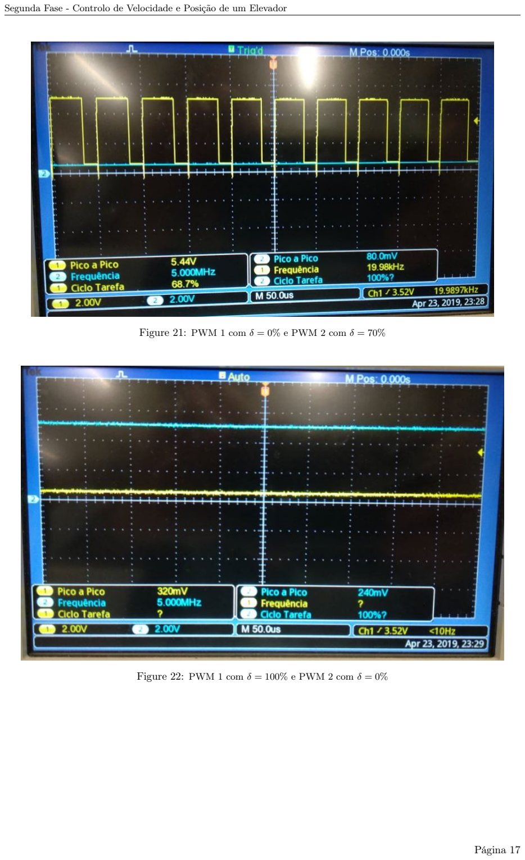
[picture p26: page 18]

Figure 21: PWM 1 com δ = 0% e PWM 2 com δ = 70%

Figure 22: PWM 1 com δ = 100% e PWM 2 com δ = 0%


Figure 23: PWM 1 com δ = 0% e PWM 2 com δ = 100%

Figure 24: PWM 1 com δ = 50% e PWM 2 com δ = 50%

Análise:

Quanto à forma dos sinais os resultados obtidos estão de acordo com as expectativas. Com um duty cycle de 100% obtem-se uma tensão constante de 5V, com 0% um tensão constante de cerca de 0V. De seguida, analisando o movimento do elevador, com as duas ondas com duty cycle de 50% o motor como previsto não possui movimento pois os dois sinais iram-se anular e o encoder terá sinal resultante nulo. Também se observou que quanto maior o duty cycle da onda, maior será a velocidade do encoder. Quanto ao sentido do seu movimento, se o duty cycle da PWM1 é maior que o a da segunda, o elevador desce. Inversamente quando o duty cycle da PWM2 é maior que o da um, o elevador sobe.
Portanto quanto ao movimento do elevador os resultados obtidos vão de encontro com o esperado e estão corretos.

### 6.3 Testes da leitura da tensão dos sensores de efeito de Hall e deteção de piso

Objetivo:

Verificação do bom funcionamento dos sensores de efeito de Hall, da sua leitura por parte da ADC do microcontrolador (Arquitetura de Software - ADC), o uso do módulo da UART (Arquitetura de Software -UART) e finalmente da correta deteção de cada andar pelos sensores de efeito de Hall.

Descrição e Resultados Esperados:

Para testar os sensores de efeito de Hall, foi feita a montagem partindo do esquema elétrico da secção Descrição do Hardaware - Sensor de Efeito de Hall. O pino 6 ligou-se a 5V, o 1 à massa e os pinos 5 a 2 foram ligádos ao microcontrolador nos portos AN0 a AN3.
Utilizando as funções initADCTimer, initADC , buffer e InitUART fez-se o display das leituras no terminal do valor do buffer da ADC. Numa primeira aproximação variou-se a posição do elevador à mão e viu-se a resposta do valor do buffer consoante a proximidade do íman do elevador com os sensores de efeito de Hall. Após algumas tentativas conseguiu-se encontrar uma gama para a qual o valor do buffer é consistente com a proximidade do elevador ao sensor de efeito de Hall. Também se sabe que a tensão de saída referencia dos sensores é 2.5V e com a proximidade do iman instalado a sua tensão baixa para cerca de 2.4 Logo a partir daí já se consegue determinar o andar em que o elevador se encontrar graças à leitura da tensão produzida pelos sensores de Hall. Utilizando o módulo da UART fez-se o display do andar em causa, cada vez que o microcontrolador deteta um valor do buffer na gama escolhida.
É expectável que o microcontrolador, consiga fazer, a leitura correta dos sensores, a deteção certa do andar em que o elevador se encontra e que o módulo da UART funcione corretamente.

Resultados:

Utilizando as funções já enunciadas na secção anterior, o Putty para a leitura da UART e fazendo variar a posição do elevador à pão. Obteve-se os seguintes resultados no terminal do computador:


(a) Sem campo magnético
(b) Com campo magnético

Figure 25: Tensão produzida pelo Sensor de Efeito de Hall

Figure 26: Deteção do Andar 1

Figure 27: Deteção do Andar 2

Figure 28: Deteção do Andar 3


Figure 29: Deteção do Andar 4

Análise:

O microcontrolador consegue localizar com alguma exatidão e precisão o andar em que o elevador se encontra. Na próxima fase iremos aumentar ainda mais a precisão da deteção do piso do elevador.
Portanto os resultados obtidos foram de encontro ao esperado e estão corretos.

### 6.4 Testes da leitura dos botões e bottom switch

Objetivo:

Verificação da correta leitura do estado dos quatro botões e do bottom switch instalado no elevador.

Descrição e Resultados Esperados:

Para testar os botões, fez-se a montagem partindo do esquema elétrico da secção Descrição do Hardaware -Botões.
Utilizando as funções InitButtons, PushButton0 , PushButton1, PushButton2, PushButton3 e BottomSwitch fez-se a leitura do estado do porto e consequentemente o display do estado de cada botão quando premido pelo utilizador.
É expectável que o microcontrolador, consiga fazer a leitura do estado do porto e o display do estado pelo módulo da UART.

Resultados:

Utilizando as funções já enunciadas na secção anterior e o Putty para a leitura da UART. Obteve-se os seguintes resultados no terminal do computador:


Figure 30: Leitura do Bottom Switch

Figure 31: Leitura do Botão 1

Figure 32: Leitura do Botão 2

Figure 33: Leitura do Botão 3


Figure 34: Leitura do Botão 4

Análise:

O microcontrolador consegue com sucesso detetar o estado de cada botão. O que permite na próxima fase interligar o estado do botão com o andar escolhido pelo utilizador.
Concluindo os resultados obtidos foram de encontro ao esperado e estão corretos.

### 6.5 Testes da leitura dos canais do Encoder

Objetivo:

Verificação da correta leitura do estado dos três canais do Encoder pelo microcontrolador.

Descrição e Resultados Esperados:

Para testar os botões, fez-se a montagem exposta na secção Descrição do Hardaware - Encoder, ligando cada canal do encoder a um porto do microcontrolador com interrupções externas.
Utilizando as funções SetEncoderPorts, SetExternalInt0 e SetExternalInt1, SetExternalInt2 fez-se a leitura dos três canais e por fim o display do estado de cada um.
É expectável que o microcontrolador, consiga fazer a leitura correta do estado de cada canal e o display deste mesmo. A interrupção do canal Z apenas vai ser executada quando o elevador deixar de ter movimento, pois nesse instante o estado do canal Z muda. Também se espera que no sentido descendente o sinal do Canal B esteja adiantado em relação ao A, no sentido contrario o sinal do Canal B estará atrasado. Quanto ao Canal Z deve estar a HIGH enquanto o elevador possuir movimento, independentemente do sentido de rotação.

Resultados:

Utilizando as funções já enunciadas na secção anterior,o Putty para a leitura da UART e o osciloscópio da bancada para medir os sinais. Obteve-se os seguintes resultados:


Figure 35: Canal A(Ch1) e B(Ch2), sentido descendente

Figure 36: Canal A(Ch1) e B(Ch2), sentido ascendente


Figure 37: Canal A(Ch1) e Z(Ch2), sentido descendente

Figure 38: Canal A(Ch1) e Z(Ch2), sentido ascendente


Figure 39: Deteção da interrupção externa do canal A

Figure 40: Deteção da interrupção externa do canal B

Figure 41: Deteção da interrupção externa do canal Z

Análise:

Quanto aos sinais lidos pelo osciloscópio vão de encontro ao esperado pelo que existe uma oscilação de 50Hz, que pensamos ser da rede que alimenta a fonte de tensão. O microcontrolador consegue com sucesso detetar o estado de cada canal do Encoder, pelo que executa as interrupções do Canal A e B e apenas executa a do Canal Z quando se pára o movimento do elevador. A leitura dos canais, permite na próxima fase determinar o sentido de rotação do encoder e por consequência a posição e velocidade do elevador.
Concluindo os resultados obtidos foram de encontro ao esperado, mas a oscilação da fonte de tensão vai ter que ser eliminada para podermos fazer uma leitura o mais correta do estado.

## 7 Memória Descritiva

O objetivo principal deste projeto é a realização de um sistema que controle a posição e velocidade de um elevador. Para tal a primeira meta que definimos foi analisar o hardware já dado pelo prototipo do elevador e como controlar o encoder. Concluiu-se que o encoder funciona com sinais PWM e recorrendo a uma ponte H consegue-se controlar o sentido do movimento do encoder. Quanto à velocidade, quanto maior o duty cyle do sinal PWM, maior será a velocidade.
Portanto já sabendo como controlar a velocidade e posição do encoder, tem de se escolher um integrado para controlar o encoder. Para isso usando a sugestão do docente usou-se o L293, que é, um componente muito comum no controlo de motores. Analisando o datasheet do componente, evidenciou-se que para funcionar é preciso um sinal TTL com tensão mínima de 4.5 V e é capaz de fornecer uma corrente de 1 A nas suas saídas. Surge a questão de como geral um sinal TTL de tensão mínima de 4.5V, para isso recorrendo mais uma vez à sugestão do docente, configurando as saídas do microcontrolador em open drain e com um pull up resistor consegue-se produzir sinais com uma tensão de 5V. Desta maneira consegue-se aplicar estes sinais diretamente do microcontrolador para o integrado sem recurso a hardware adicional. Posto isto foi desenvolvido o módulo da PWM que cria dois sinais PWM com a opção de escolha do duty cycle de cada uma. Para impor uma frequência aos sinais foi usado o Timer2 para ambas. De seguida fez-se uma montagem simples para o teste dos sinais de acordo com a secção Descrição do Hardware - Driver do Motor . Para boa prática foram adicionados quatro diodos responsáveis por minimizar o efeito dos picos de tensão devidos ao efeito indutor do motor. Foi escolhido o modelo BA157 para os diodos, pois são indicados para elevadas velocidades de comutação. Após os testes bem sucedidos, referidos na secção Testes e Resultados - Testes da ponte H e movimento do elevador deu-se por concluído o desenvolvimento deste módulo. Foi observado o aumento da velocidade do elevador com o aumento do duty cycle e a variação do sentido do movimento do elevador com os sinais produzidos pelo microcontrolador.
Partiu-se então, para a leitura do estado dos quatro botões e o do bottom switch. A utilidade dos quatro botões será para que o utilizador escolha o nível que deseja e o bottom switch para indicar a permanência do elevador no nível 1. Este último poderá ser útil, no futuro, quando for desenvolvida a rotina da calibração do elevador. Sendo que, alerta o sistema que o elevador se encontra na posição zero dando fim à calibração. Quanto ao software de leitura, foi desenvolvido o módulo PushButtons, que de uma maneira simples lê o estado do porto a que cada interruptor está ligado. Este lê o estado HIGH quando os interruptores estão premidos e LOW no caso contrário. Para o display do estado destas entradas é preciso a comunicação via terminal. Logo paralelamente foi desenvolvido o módulo UART, que resolve essa necessidade.
Depois virou-se a nossa atenção para os sensores de Hall. Tem-se um por cada andar, num total quatro. Após uma leitura e investigação do funcionamento deste tipo especifico de sensores, concluiu-se que a sua tensão varia com a proximidade a um campo magnético, neste caso dado por um íman colado à parte inferior da caixa do elevador. Portanto o microcontrolador vai ter que ler esta variação de tensão, para isso desenvolveu-se o módulo ADC que permite a leitura de quatro portas analógicas ao mesmo tempo e com a ajuda do Timer 3 impõe-se uma frequência de amostragem de 400Hz nas leituras. Ligando a alimentação aos sensores e a saída de cada um ao microcontrolador, conseguiu-se ler o valor do buffer de cada entrada e a partir daí, chegar a uma gama de variação para a qual o iman se encontra na proximidade do sensor. Por outras palavras que o elevador se situa no andar específico. Por fim referindo os testes na secção Testes e Resultados - Testes sensores de Hall, o microcontrolador consegue decidir o andar em que se situa o elevador com alguma exatidão e precisão. Como já referido anteriormente, a precisão da leitura vai ser ainda melhorada, na ultima fase do projeto, para obtermos o melhor resultado possível.
Quanto ao funcionamento do encoder, teve-se de pensar numa estratégia para se determinar o sentido de rotação do motor e mais tarde a posição. Para isso após alguma investigação do funcionamento de encoderes incrementais, pensou-se em ter uma interrupção externa por cada canal do encoder (A,B e Z). Cada interrupção é iniciada com a deteção de uma raising edge, logo nesse momento o microcontrolador lê o estado do canal e inverte o funcionamento da interrupção para falling edge. Portanto consegue-se ler o estado de cada canal, invertendo o funcionamento da interrupção entre raising edge e falling edge. Fez-se uma simples montagem para ler os canais e deparámo-nos rapidamente com um problema. o canal B e Z possuíam muito ruído, o que faz com que a deteção de mudança de nível seja incerta e não correta pelo microcontrolador. Mais tarde descobriu-se que o setup da nossa sala se encontrava danificado pois não permitia fazer uma leitura sem ruído dos canais. Logo usando o setup da outra sala conseguimos obter leituras corretas dos canais A,B e Z, apesar de estes estarem com uma oscilação vinda da fonte de alimentação. Quanto ao módulo desenvolvido para o encoder as interrupções externas funcionam corretamente, apenas se tem na próxima fase de eliminar a oscilação de 50Hz dos canais B e Z. A partir daí já temos as rotinas escritas para o calculo da posição e velocidade do elevador. A rotina para o calculo da velocidade implementa um timer com uma frequência de amostragem e mede-se a diferença da posição entre esse intervalo de amostragem. A partir daí calcula-se a velocidade sabendo a variação da posição e de tempo. O algoritmo da posição compara o estado do canal A e B, se estes forem diferentes incrementa a posição se forem iguais decrementa a posição.
Por fim o ultimo módulo a desenvolver é o responsável pelo display do andar em que o elevador se encontra e a sua velocidade. O módulo do LCD ainda não se encontra totalmente desenvolvido e funcional, devido à sua complexidade imprevista.

## 8 Conclusão

Quanto à segunda fase atingimos quase por completo os objetivos impostos pelo guião da disciplina, sendo estes a apresentação dos testes feitos, desenvolvimento do software base na sua totalidade e montagem total do hardware. O módulo que ficou por acabar foi o do display LCD, que acaba por ter menos prioridade do que os outros módulos responsáveis pelo funcionamento pleno do sistema do elevador.
No futuro podem haver alterações no que foi apresentado nesta segunda fase. Pois na fase seguinte, procede-se ao desenvolvimento por completo do sistema de controlo do elevador. As possíveis alterações serão apresentadas, em versões atualizadas no relatório da terceia fase.

## 9 Bibliografia

Apontamentos de Sistemas de Instrumentação Eletrónica, fornecidos pelo docente.

Esquema do Elevador,
https://elearning.ua.pt/pluginfile.php/962673/mod_resource/content/1/praticas/trabalhos/t4/elevador. pdf (https://elearning.ua.pt/pluginfile.php/962673/mod_resource/content/1/praticas/trabalhos/t4/elevador.pdf)
OMRON ,Rotary Encoder E6B2 Datasheet, https://elearning.ua.pt/pluginfile.php/962676/mod_resource/content/1/praticas/trabalhos/t4/omrom_e6b2.pdf (https://elearning.ua.pt/pluginfile.php/962676/mod_resource/content/1/praticas/trabalhos/t4/omrom_e6b2.pdf)
SGS-THOMSON MICROELECTRONICS, l293B,L293E, Datasheet, https://elearning.ua.pt/pluginfile.php/962679/mod_resource/content/1/praticas/trabalhos/t4/l293. pdf (https://elearning.ua.pt/pluginfile.php/962679/mod_resource/content/1/praticas/trabalhos/t4/l293.pdf)
HONEYWELL,SS495A-S,Datasheet https://sensing.honeywell.com/honeywell-sensing-sensors-linear-hall-effect-ics-ss490-series-\ datasheet-005843-2-en.pdf
Manual de referência online da Max32 Digilent, https://elearning.ua.pt/pluginfile.php/963675/mod_resource/content/1/chipkit-max32_rm.pdf

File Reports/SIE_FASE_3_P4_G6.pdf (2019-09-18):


### Departamento de electrónica, telecomunicações e informática

Curso | 8204 - Mestrado Integrado em Engenharia Electrónica e Telecomunicações
Disciplina | 41489 - Sistemas de Instrumentação Eletrónica
Ano Lectivo 2018/2019

# Terceira Fase

## Trabalho 4 - Controlo de Velocidade e Posição de um Elevador

Autores:

76517 | João André de Jesus Cruz
76674 | Henrique da Silva Bernardes Camello Martins
Turma | P4
Grupo | G6
Data | 1 de Julho de 2019
Docente | Pedro Fonseca

Fase três - Controlo de Velocidade e Posição de um Elevador

### Conteúdo

1 Introdução | 2
2 Descrição do Problema | 2
3 Equipamentos | 3
4 Procedimento | 3
5 Testes, Resultados e Análise | 9
6 Conclusão | 12
7 Bibliografia | 13
8 Anexos | 15

### 1 Introdução

Este projeto a ser realizado no contexto das aulas práticas de Sistemas de Instrumentação Eletrónica, tem como objetivo, o controlo da posição e velocidade de um elevador. Para isso, foi desenvolvido um sistema baseado num microcontrolador sendo este mesmo o Max32 Digilent. Quanto ao funcionamento do elevador, resumidamente este está acoplado a um sistema cabo roldana, que está ligado a um motor e que tem o seu veio ligado a um codificador incremental bi-fásico.
A velocidade e posição do elevador, será controlada pelo microcontrolador. A escolha da posição será feita pelo utilizador. Quanto à velocidade, essa será controlada de acordo com um perfil calculado.
Nesta fase foi desenvolvido o resto do software que faltou da segunda fase nomeadamente o controlo do LCD, a posição, velocidade do encoder e o controlador PI. Este relatório referente à terceira fase apresenta o resto do software desenvolvido, resultados finais e conclusões.

### 2 Descrição do Problema

Revendo os objetivos do projeto o que se pretende é o controlo da posição e da velocidade de um elevador, este mesmo pode funcionar em duas direções diferentes (para baixo e cima), é usada uma ponte H que faz com que o motor varie o sentido de rotação conforme o sinal PWN recebido. O utilizador, como já referido na Introdução irá interagir com o sistema, podendo escolher a posição. A velocidade e a posição irá ser apresentada num display LCD.
Na terceira fase, tem-se como objetivos o controlo da posição e velocidade do elevador e um controlador PI para o controlo do motor.

### 2.1 Objetivos do Projeto:

- Definição do ponto de chegada em coordenadas do encoder.
- Capacidade de programação dos parâmetros Vmax, Vapr e Dapr com configuração automática dos perfis
- Capacidade de alimentação de motor DC (5V / 1W).
- Encoder bi-fásico com saída TTL e 500 ipr
- Deteção de piso por sensor de proximidade (efeito de hall), com auto-calibração.
- Adicionalmente: capacidade de programação dos parâmetros do controlador.
- Medição da corrente consumida.

### 3 Equipamentos

- 4xDíodo BA157
- Potenciómetro 10kΩ
- Condensador 100uF
- Díodo Zener 2V4
- Condensador 0.1uF
- Driver de Motor L293NE
- Condensador 100uF
- OpAmp TL084
- 3xResistência 1kΩ
- 5xPushbuttons
- 16xResistência 10kΩ
- LCD 1602a
- 8xResistência 330kΩ
- Ficha DB9M
- Resistência 220Ω
- Resistência 560Ω
- Fios
- Fonte de Alimentação do laboratório
- Osciloscópio

### 4 Procedimento

### 4.1 Arquitetura de Software

Nesta secção do relatório da fase três, são apresentados os últimos device drivers, o controlador PI mais fluxogramas que ajudam a compreender o seu funcionamento.
As funções suplementares desenvolvidas foram:

external_isr_3(void)

### 4.1.1 Calculo da Posição

Sabendo que temos de controlar a posição do elevador, o cálculo das coordenadas do encoder é vital no bom funcionamento do controlador PI anteriormente exposto. No relatório da fase 2 teve-se um problema na leitura dos canais do encoder, em que aparecia uma oscilação de 50 Hz. Esta oscilação foi identificada como um problema de massas, que foi resolvido ligando as massas todas juntas.
Com a abordagem da fase anterior, para o calculo da posição, tinha-se uma contagem da posição com baixa repetibilidade, o que faz com a contagem seja inválida. Este facto foi verificado na prática com a ajuda do docente, ativando uma saída antes do printf e desativando logo a seguir à instrução. Recorrendo ao osciloscópio no canal 1 mediu-se o Canal A do encoder e no Canal B o pino da saída configurada. Por fim executando o código verificou-se uma perda de contagens elevada, pois este printf dentro da rotina de interrupção do Timer causa um atraso significativo e com efeito pouco previsível nas contagens. Para solucionar este problema, pode-se colocar o print das contagens dentro de um ciclo while na main. Executando de novo o software, observou-se, deslocando o elevador para cima e baixo, que o valor da posição, agora é válido. Alterando o sentido da rotação e fazendo várias repetições têm-se valores consistentes e com repetibilidade.
Quanto à estratégia da obtenção das contagens, mantém-se o mesmo procedimento da fase 2, apenas se fez um diagrama de fluxo adicional, para expor com a maior clareza o seu funcionamento, Anexos - Diagrama de Fluxo Calculo da Posição.

### 4.1.2 Escolha do Andar

Como já referido na fase 1, o utilizador irá escolher o andar desejado com recurso a botões. Para isso tem-se que ter a leitura do estado dos botões e a contagem da posição do elevador. A leitura do estado dos botões foi desenvolvida com sucesso na fase 2, o processo das contagens foi corrigido nesta ultima fase como explicado anteriormente.
Posto isto, sinteticamente o que esta rotina vai fazer é atribuir um valor de setpoint a cada andar, sendo esta variável do tipo volatile. Por exemplo, quando o utilizador prime o botão correspondente ao ultimo andar, atribui ao setpoint o valor da coordenada do encoder que coincide com o ultimo piso. Portanto como referido, no sub capitulo anterior, a contagem da posição é vital para o bom funcionamento do sistema.
A obtenção dos valores dos setpoints foi feita da seguinte maneira: fez-se um breakpoint na função de retorno do valor da contagem ( GetPos() ) e colocou-se o elevador a mover-se até ao piso desejado. No momento em que o elevador se encontra no piso, parou-se o movimento e passando o cursor do rato na variável da contagem tirou-se o valor da posição para cada andar. O software foi executado com a opção do MPLAB "Debug Main Project".
Concluindo têm-se quatro botões um para cada andar, cada um com o seu valor de setpoint dentro de uma rotina de interrupção de um timer com frequência de cerca de 10 Hz. Para maior clareza tem-se o diagrama de fluxo, Anexos - Diagrama de Fluxo Escolha do Andar.

### 4.1.3 Controlador PI

Para o controlo da posição e velocidade usou-se um controlador PI. Com base nos conceitos adquiridos nas UC de controlo construiu-se o controlador. Para calcular os parâmetros discretos deste controlador, colocou-se o elevador a subir e a descer. A posição foi retirada utilizando o modulo da UART e com um script simples no Matlab fez-se o calculo dos parâmetros do controlador. Desta maneira obtêm-se com precisão os valores para as constantes.
Após calculados os parâmetros implementou-se o controlador PI tal como se pretende. Para que o sistema funcione corretamente, deve ser executado de forma sequencial. Isto é, em primeiro lugar lê-se o valor do SetPoint e a Posição atual, e apenas de seguida se devem passar os parâmetros para o controlados, depois de este calcular o sinal de controlo adequado é que se deve atuar sobre os sinais PWM que tem o controlo sobre o motor. Não seguir esta sequencia poderá não trazer problemas no entanto a precisão do funcionamento do elevador será menor, uma vez que os sinais poderão estar a ser lidos já depois de, por exemplo, ter passado o SetPoint e assim a atuação irá ser feita fora do local que se pretende.
Numa primeira abordagem fez-se a execução do controlador PI, sem considerar a desaceleração do elevador na chegada ao piso destino. Tendo o valor dos setpoints e a função da posição a funcionar corretamente, obteve-se com sucesso o deslocamento do elevador para todos os pisos, sempre com precisão na chegada tanto para cima como para baixo.
Agora considerando a desaceleração do elevador na chegada ao piso destino, decidiu-se utilizar os sensores de Hall para efetuar a deteção do elevador na proximidade do piso. Com esta abordagem e com os device drivers da segunda fase da leitura da tensão dos sensores, pode-se com simplicidade saber a presença ou não do elevador no piso.

Quando a posição se aproxima do setpoint, os sensores de Hall começam a fazer o controlo da velocidade do sinal. Como já foi mencionado nos relatórios anteriores e como é feito mais à frente dos sensores de Hall, temos uma tensão média de 2.5V, quando dos afastamos deste a tensão aumenta. Com um circuito de acondicionamento e a leitura dos valores na ADC permite obter o valor do sinal entre 0 e 1023, a partir do qual conseguimos desacelerar o elevador assim que este se aproxima da posição do sensor de Hall.

Figura 1: Diagrama de um controlador PI

### 4.1.4 External_isr_3(void)

Esta rotina tem como função fazer a calibração do elevador, faz o reset aos parâmetros do controlador PI, da sua posição e também coloca o elevador no piso zero. Logo para isso, decidiu-se usar um pino de interrupção externa que tem ligado a si um botão.
A rotina da interrupção é executada quando se prime o botão de reset, a partir daí gera-se a PWM1 com um duty cycle 100 e a PWM2 com 0, desta maneira o elevador desce. O movimento mantém-se enquanto o bottom switch não for premido, no momento em que é premido o movimento cessa colocando o duty cycle das duas PWM a 0 e faz-se a reiniciação dos parâmetros do controlador PI. Para maior clareza tem-se o diagrama de fluxo, Anexos - Diagrama de Fluxo Função da Calibração.

### 4.1.5 LCD

Como já foi mencionado e descrito na fase anterior deste trabalho e é visível no diagrama de fluxo que se segue, para o correcto funcionamento do LCD é necessário, em primeiro lugar é necessário definir os portos do microcontrolador que se irão usar, de seguida é necessário fazer a correcta inicialização dos modos de operação, neste caso em específico deve ser executado sequencialmente os seguintes comandos, sempre que inicializado o display, Reset do display, Set do modo 4bits e 2 linhas, Desligar o cursor e por fim colocar no entry mode. Cada uma das formas de implementação pode ser consultada no datasheet do LCD [7]. Após a iniciação do LCD, é feito na função main o update da linha 1 do LCD, na linha 2 apenas é feito o update se for premido algum botão para mover o elevador, e nesse caso imprime qual é o próximo andar, ou no caso de ser premido o botão de calibração, que imprime uma mensagem a informar que o elevador está a ser calibrado. Este ciclo repete-se sempre que for premido um novo botão. Anexos - Diagrama de Fluxo de funcionamento do LCD.
Um dos problemas que enfrentamos na segunda fase do projecto e também ao decorrer da fase 3, foi o facto de não ser possível utilizar o LCD ao mesmo tempo que a UART, ora, isso deveu-se ao facto de aquando da escolha dos pinos de dados para o LCD um deles ser o pino 0 do kit, que está sabém a ser utilizado pela UART, sendo que isso não permitia que se usassem os 2 pinos em simultanêo, pelo que para resolver esta situação apenas foi necessário atribuir novos pinos aos pinos de dados.

### 4.2 Hardware

Quanto a alterações de Hardware permaneceu tudo na mesma em relação às fases anteriores. Apenas propomos um circuito de acondicionamento de sinal dos sensores de Hall, para a maximização da resolução da ADC.

### 4.2.1 Circuito de Acondicionamento dos Sensores de Hall

Posto isto a partir do estudo do comportamento dos sensores de Hall na fase 2, tem-se resumidamente: tensão referencia 2.5(V) e tensão com a proximidade de um campo magnético 2.4(V). Portanto com uma tensão de 2.4(V) sabe-se que o elevador está no andar em questão.
Logo no caso de se ligar os sensores de Hall diretamente à ADC da PIC32 tem-se a seguinte resolução:

VADC,1 =

VHall,1 ∗ 2

10

3.3

=

2.5 ∗ 2

10

3.3

= 776

VADC,2 =

VHall,2 ∗ 2

10

3.3

=

2.4 ∗ 2

10

3.3

= 745

ResADC =

2.5 − 2.4
776 − 745

= 3(mV )

Portanto tem-se uma resolução de 3 mV com a ligação direta à ADC. Esta foi a implementação escolhida no projeto.
No caso de se querer maximizar a resolução dos sensores, tem de se projetar um circuito de acondicionamento de sinal. Este mesmo tem de ter uma tensão de offset que vai ser subtraída à tensão do sensor e por fim um ganho adequado para maximizar a resolução. Na figura seguinte tem-se a cadeia de acondicionamento de sinal por blocos, mais o circuito.


Figura 2: Acondicionamento do Sinal

Para se ter o ganho de 33 (V/V) e sabendo que o ganho do amplificador é:

Av =

R2
R1

<=> R2 = R4 = 330kΩ, R1 = R3 = 10kΩ

Se

(R2 = R4, R1 = R3)

Para gerar a tensão de referencia pode-se usar o circuito seguinte:


Figura 3: Circuito Gerador da Tensão Referencia

Em que Vz pode ser um díodo de zener de 3.3(V) e Vss os 5(V) da PIC32. Tem-se então:

R1 =

Vss−Vz
Iz

<=>

5−3.3
15m <=> R1 = 113Ω
V0 =

R3
R3+R2

∗ Vz <=> 2.4 = R3 R3+R2
∗ 3.3 <=> R3 = 2.597 ∗ R2

Por fim têm-se os gráficos com as relações todas de tensões, resumindo toda a cadeia de acondicionamento de sinal mais o calculo da resolução.


Figura 4: Relações entre as tensões

VADC,1 =

VHall,1 ∗ 2

10

3.3

=

3.3 ∗ 2

10

3.3

= 1023

VADC,2 =

VHall,2 ∗ 2

10

3.3

=

0 ∗ 2

10

3.3

= 0

ResADC =

2.5 − 2.4
1023

= 98(µV )

Concluindo desta maneira tem-se a maior resolução possível. Apesar da melhoria evidente na resolução da leitura, vem um acrescento ao custo do projeto. Decidiu-se que este custo adicional e hardware não seria necessário pois consegue-se produzir um resultado satisfatório com os sensores ligados diretamente à PIC32.
Apesar de tudo esta configuração pode ser útil, numa situação mais exigente, em que se quer a melhor deteção da aproximação do elevador ao piso.

### 5 Testes, Resultados e Análise

### 5.1 Testes da Contagem da Posição do Elevador

Objetivo:

Este teste tem como objetivo verificar, se a contagem da posição elevador é correta. E retirar o valor do setpoint de cada andar.

Descrição e Resultados Esperados:

Devido ao problema anteriormente referido da perda de contagens utilizando a função printf. Utilizou-se a opção do MPLAB "Debug Main Project"com um breakpoint na função GetPos() que retorna o valor do incremento que equivale a posição. Desta maneira colocou-se o elevador em movimento até à posição desejada e parava-se o movimento. De seguida passou-se o cursor na variável da contagem e consegue-se ver o valor da variável. Fez-se este procedimento para cada andar. É expectável conseguir-se retirar o valor correto da posição para cada andar. Correto quer dizer-se um valor com repetibilidade e sem perda de contagens.

Resultados:

Recorrendo à ferramenta "Debug Main Project"obtiveram-se os seguintes valores da posição para cada andar:

Andar | Posição
0 | 0
1 | 3090
2 | 5997
3 | 9063

Análise:

Os valores da posição foram obtidos repetindo o teste várias vezes e obtiveram-se valores sempre da ordem dos apresentados na tabela anterior. Portanto conclui-se que a contagem faz-se sem perdas e dando valores corretos consequentemente.

### 5.2 Testes do Controlador PI

Objetivo:

Este teste tem como objetivo verificar, se o controlador PI implementado funciona corretamente, colocando o elevador no andar escolhido pelo utilizador.

Descrição e Resultados Esperados:

Utilizando os valores de setpoint retirados na secção anterior de testes implementou-se o controlador PI. Fez-se a seleção de todos os andares, tanto a subir como a descer. É expectável que o elevador consiga deslocar-se para qualquer andar, sem perda de precisão no ponto de chegada.

Resultados:

Após a execução do software com o controlador PI, testou-se todos os caminhos que o elevador podia tomar. De seguida tem-se uma tabela com os teste feitos:

Andar Inicial | Andar Final | Sentido | Sucesso
0 | 1 | Subida | Sim
0 | 2 | Subida
0 | 3 | Subida
1 | 0 | Descida
1 | 2 | Subida
1 | 3 | Subida
2 | 0 | Descida
2 | 1 | Descida
2 | 3 | Subida
3 | 0 | Descida
3 | 2 | Descida
3 | 1 | Descida

Análise:

Conclui-se que o controlador PI funciona corretamente, pois o elevador consegue deslocar-se para qualquer andar e com precisão na paragem no piso desejado.

### 5.3 Testes do LCD

Objetivo:

Este teste tem como objetivo verificar o bom funcionamento do LCD.

Descrição e Resultados Esperados:

Foi configurado o LCD para usar as duas linhas do display. Na primeira linha permanentemente estará impressa a string "Bem-Vindo", na segunda dependendo do botão premido apresentará as strings: "Andar 0", "Andar 1", "Andar 2", "Andar 3"e "Calibration". É expetável que apresente a string "Bem-Vindo"na primeira linha permanentemente, e depois na segunda linha as restantes strings anteriormente anunciadas dependendo do andar escolhido. A string "Calibration"é impressa se se premir o botão correspondente à função da calibração do elevador.

Resultados:


Figura 5: Display de Strings no LCD

Após a execução do software premiu-se cada botão obtendo os seguintes resultados:

Análise:

A partir das imagens anteriores concluiu-se que a impressão no LCD das strings foi feita com sucesso.

### 6 Conclusão

Quanto à terceira fase atingiu-se quase por completo os objetivos impostos pelo guião da disciplina, estando estes enumerados na secção Descrição do Problema - Objetivos. Com sucesso foram alcançados: a definição do ponto de chegada em coordenadas do encoder, capacidade de alimentação do motor DC, deteção do piso por sensor de proximidade, implementação do controlador PI e desenvolvimento de software para o controlo de um LCD com duas linhas, sendo este último um objetivo extra adicionado pelo grupo. Em falta ficou a medição da corrente consumida, capacidade de programação dos parâmetros de velocidade e distancia de aproximação.
Balanceando todo o trabalho desenvolvido, concluímos que os objetivos principais foram feitos, sendo estes, o controlo da posição e velocidade, escolha do andar pelo utilizador, leitura dos sensores de Hall, controlador PI e LCD capaz de imprimir strings.
Dando por concluído o projeto, apesar de não terem sido realizadas todas as tarefas, alcançou-se os objetivos principais deste mesmo.

## 7 Bibliografia

[1] Apontamentos de Sistemas de Instrumentação Eletrónica, fornecidos pelo docente.
[2] Esquema do Elevador,
https://elearning.ua.pt/pluginfile.php/962673/mod_resource/content/1/praticas/trabalhos/t4/elevador.pdf (https://elearning.ua.pt/pluginfile.php/962673/mod_resource/content/1/praticas/trabalhos/t4/elevador.pdf)
[3] OMRON ,Rotary Encoder E6B2 Datasheet, https://elearning.ua.pt/pluginfile.php/962676/mod_resource/content/1/praticas/trabalhos/t4/omrom_e6b2.pdf (https://elearning.ua.pt/pluginfile.php/962676/mod_resource/content/1/praticas/trabalhos/t4/omrom_e6b2.pdf)
[4] SGS-THOMSON MICROELECTRONICS, l293B,L293E, Datasheet, https://elearning.ua.pt/pluginfile.php/962679/mod_resource/content/1/praticas/trabalhos/t4/l293.pdf (https://elearning.ua.pt/pluginfile.php/962679/mod_resource/content/1/praticas/trabalhos/t4/l293.pdf)
[5] HONEYWELL,SS495A-S,Datasheet https://sensing.honeywell.com/honeywell-sensing-sensors-linear-hall-effect-ics-ss490\ -series-datasheet-005843-2-en.pdf
[6] Manual de referência online da Max32 Digilent, https://elearning.ua.pt/pluginfile.php/963675/mod_resource/content/1/chipkit-max32_rm.pdf (https://elearning.ua.pt/pluginfile.php/963675/mod_resource/content/1/chipkit-max32_rm.pdf)
[7] Manual do LCD Utilizado - 1602A http://www.eigenstudium.de/fileadmin/user_upload/Download/Datenblaetter/LCD-1602A.pdf (http://www.eigenstudium.de/fileadmin/user_upload/Download/Datenblaetter/LCD-1602A.pdf)

### 8 Anexos


Figura 6: Diagrama de fluxo do Calculo da Posição


Figura 7: Diagrama de fluxo da Escolha do Andar


Figura 8: Diagrama de Fluxo da Função Calibração


Figura 9: Diagrama de fluxo de funcionamento do LCD

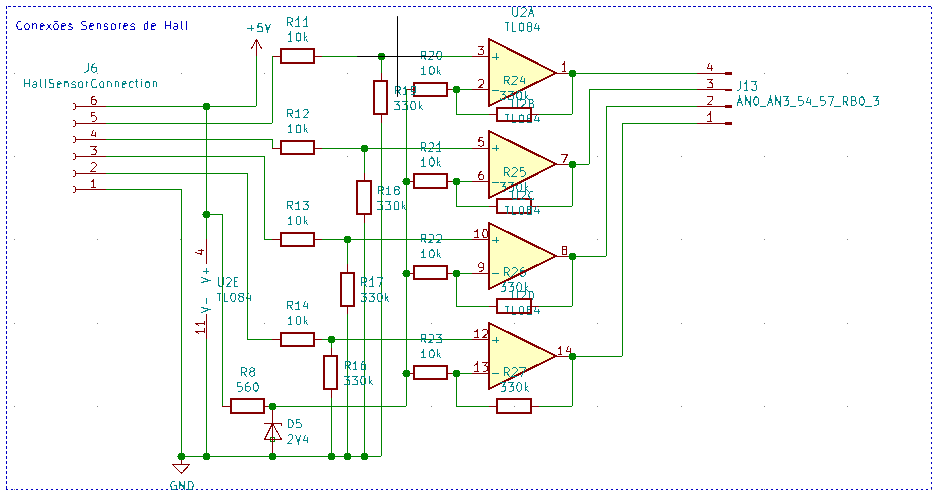
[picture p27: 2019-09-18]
Elevator_PCB/Imagens/amp.png

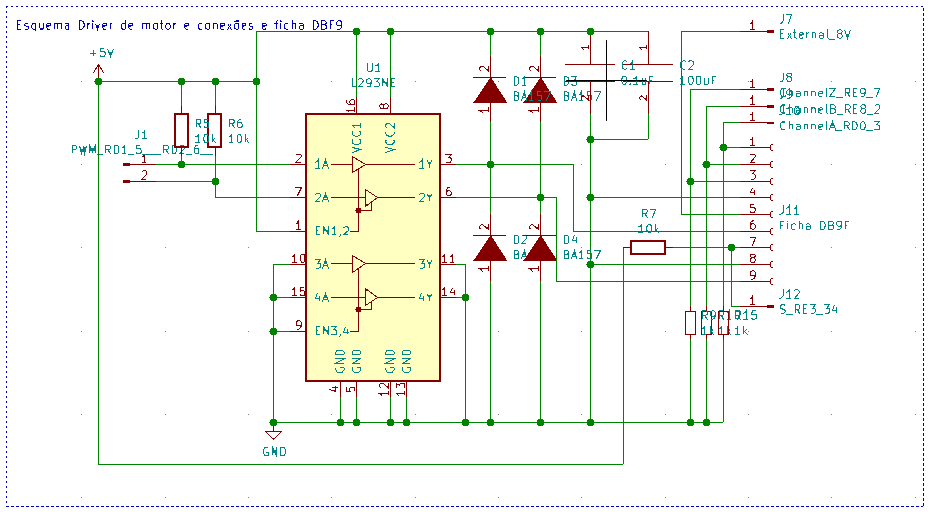
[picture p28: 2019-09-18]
Elevator_PCB/Imagens/driver_es.png

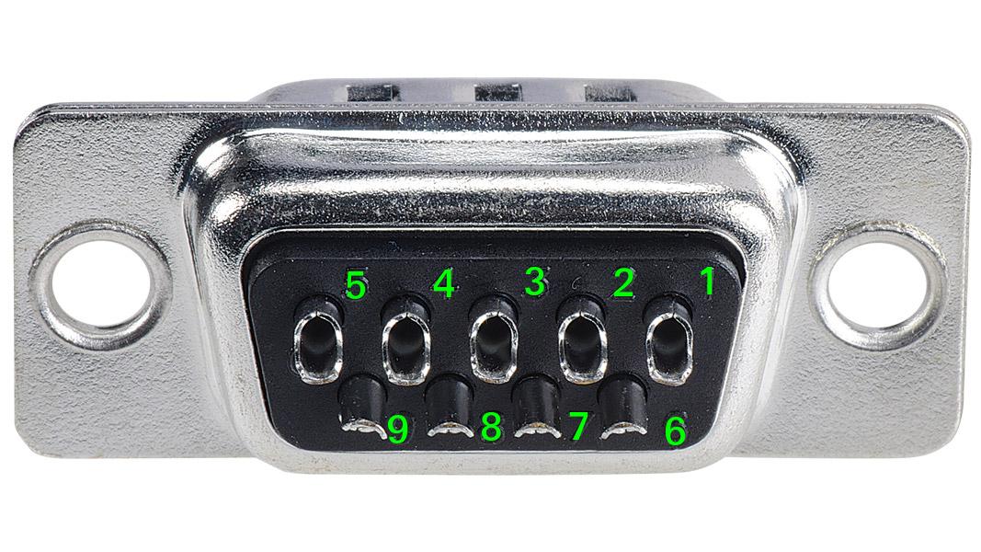
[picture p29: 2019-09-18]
Elevator_PCB/Imagens/DB9M_back.jpg

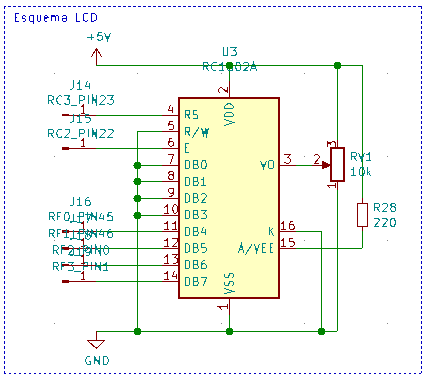
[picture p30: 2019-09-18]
Elevator_PCB/Imagens/Captura de ecrã de 2019-06-17 01-07-52.png

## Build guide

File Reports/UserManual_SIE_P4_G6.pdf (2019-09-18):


## Departamento de electrónica, telecomunicações e informática

Curso | 8204 - Mestrado Integrado em Engenharia Electrónica e Telecomunicações
Disciplina | 41489 - Sistemas de Instrumentação Eletrónica
Ano Lectivo 2018/2019

# Manual do Utilizador

## Controlo de Velocidade e Posição de um Elevador

Autores:

76517 | João André de Jesus Cruz
76674 | Henrique da Silva Bernardes Camello Martins
Turma | P4
Grupo | G6
Data | 1 de Julho de 2019
Docente | Pedro Fonseca

Manual do Utilizador - Controlo de Velocidade e Posição de um Elevador

## Conteúdo

1 Introdução | 2
2 Materiais Necessários | 2
3 Ligações no protótipo | 5
4 Carregamento do programa | 6
5 Utilização do elevador | 6

## 1 Introdução

No âmbito da unidade curricular de Sistemas de Instrumentação Eletrónica, desenvolvemos um controlador de uma elevador. Serve este documento de apoio a quem pretender replicar o projeto encontre em detalhe todos os passos a tomar, para que no final possa obter um protótipo completa-mente funcional do elevador.

## 2 Materiais Necessários

Para que o utilizador possa replicar o projeto e deverá adquirir os materiais apresentados de seguida. Em primeiro lugar, é necessário adquirir em qualquer loja de componentes eletrónicos os seguintes componentes:

- 4xDíodo BA157 | - Díodo Zener 2V4
- Condensador 100uF | - Driver de Motor L293NE
- Condensador 0.1uF | - OpAmp TL084
- Potenciómetro 10kΩ | - 4xPushbuttons
- 3xResistência 1kΩ | - LCD 1602a
- 16xResistência 10kΩ | - Ficha DB9M
- 8xResistência 330kΩ | - Headers
- Resistência 220Ω | - Fios
- Resistência 560Ω

De seguida é necessário montar o hardware, para isso pode seguir os esquemas que se seguem e montar em placa branca, ou opcionalmente, imprimir em PCB e soldar os componentes.


(a) Circuito Driver do Motor

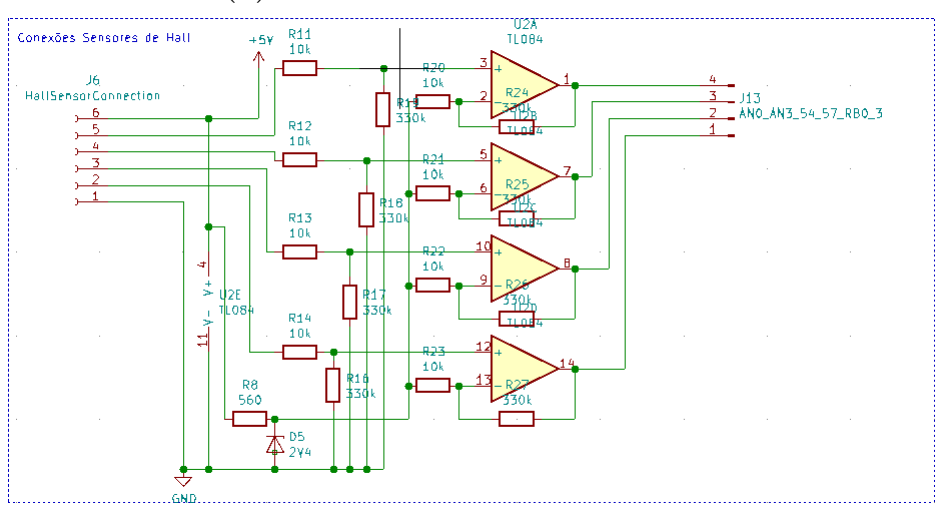
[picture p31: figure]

(b) Circuito Diferença Sensores de Hall

Figura 1: Esquema do circuito

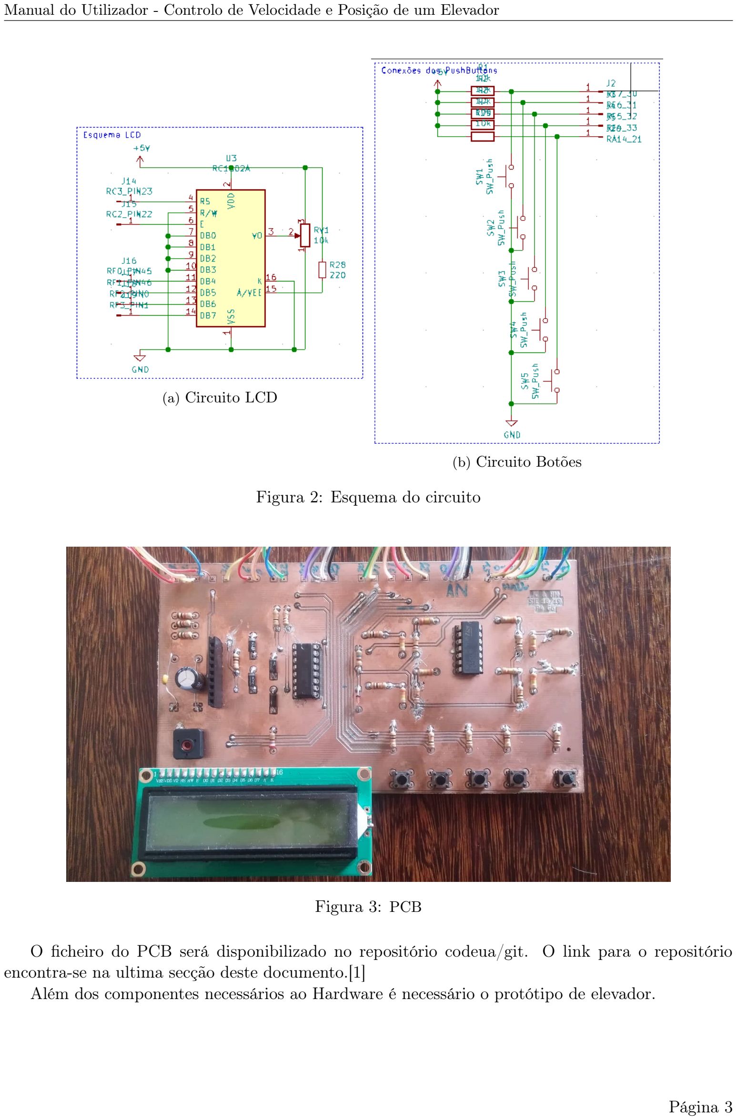
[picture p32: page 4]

(a) Circuito LCD
(b) Circuito Botões

Figura 2: Esquema do circuito

Figura 3: PCB

O ficheiro do PCB será disponibilizado no repositório codeua/git. O link para o repositório encontra-se na ultima secção deste documento.[1]
Além dos componentes necessários ao Hardware é necessário o protótipo de elevador.

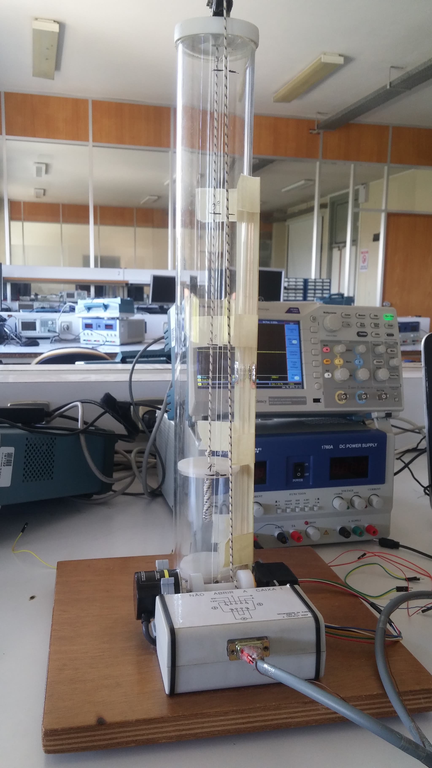
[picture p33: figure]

Figura 4: Protótipo de Elevador

E por fim a alimentação e o micro-controlador.

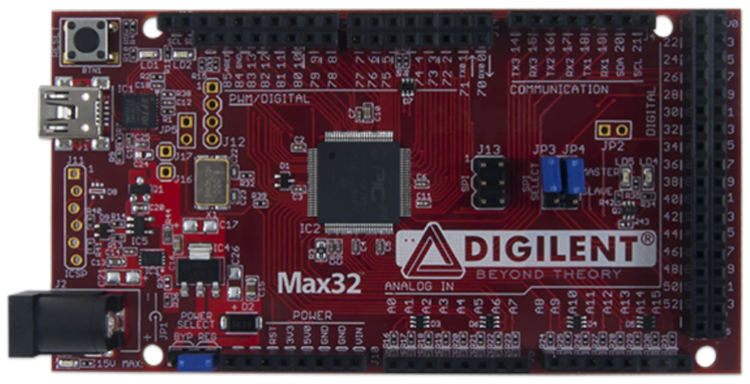
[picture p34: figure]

(a) Micro-Controlador Max32 Digilent

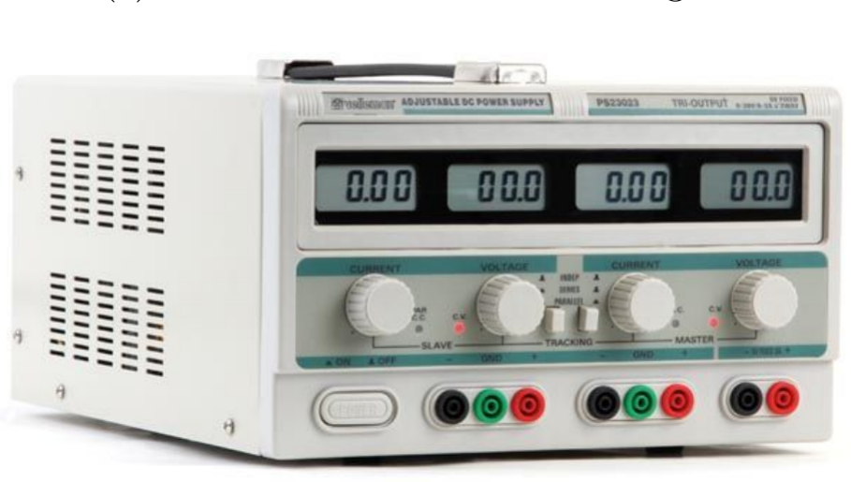
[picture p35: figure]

(b) Fonte de alimentação

Figura 5: Material adicional

## 3 Ligações no protótipo

Para garantir o funcionamento de todo o sistema é necessário efetuar corretamente todas as ligações entre os componentes, protótipo e micro-controlador.
Para ligar o protótipo ao Hardware desenvolvido é necessário utilizar a ficha DB9M, onde os pinos são depois conectados da seguinte forma:


(a) Ficha DB9M
Pino | Conexão
1 | Pino 3 MC
2 | Pino 2 MC
3 | Pino 7 MC
4 | GND
5 | +8V
6 | Motor
7 | Pino 34 MC
8 | GND
9 | Motor

Figura 6: Ligações Ficha DB9M

Os botões de escolha de nível e calibração são ligados aos pinos 30-33 e 21, respetivamente. A geração do sinal PWM é feita no micro-controlador, para que o motor entre em movimento são ligados os pinos 5 e 6, do micro-controlador, ao driver do motor, de acordo com o esquema de ligações já acima referenciado.
Os sensores de Hall são ligados ao micro-controlador por meio das portas analógicas deste, correspondendo aos pinos 54-57.
Por fim, falta apenas ligar o LCD ao micro-controlador, em que os pinos de dados do LCD DB4-DB7 são ligados aos pinos 45, 46, 0 e 25, já o RS e EN, são ligados ao pino 23 e 22, respetivamente. Todos os pinos acima mencionados estão assinalados na imagem abaixo para no caso de não estarem claras as ligações.

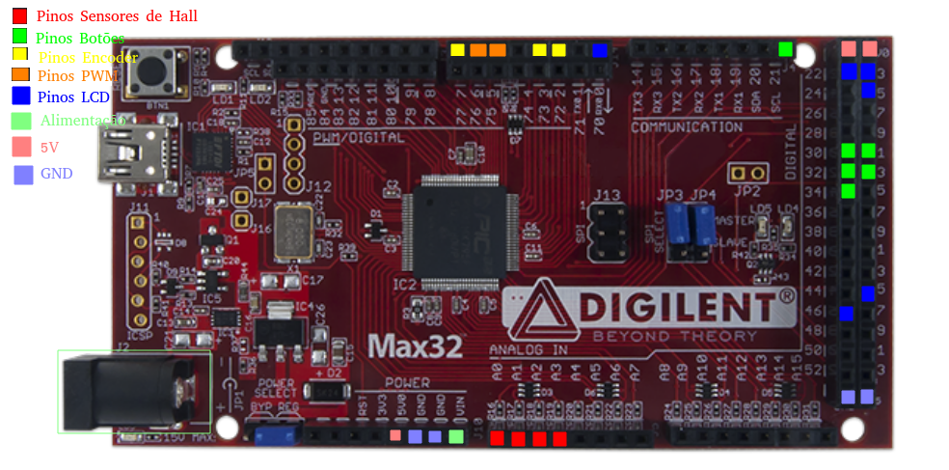
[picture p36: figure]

Figura 7: Ligações ao Micro-Controlador

No estado em que se encontra atualmente o projeto é necessário ligar o micro-controlador via USB ao computador para que seja possível alimentar a 5V os componentes necessários. Futuramente poderá alimentar-se o kit por via da porta Vin/DCJack, deixando a partir daí de se precisar da ligação USB. Todos os pinos mencionados estão assinalados acima.

## 4 Carregamento do programa

O último passo a tomar antes de poder começar a interagir com o protótipo do elevador trata do carregamento do programa para o micro-controlador. Em primeiro lugar deve ir à página do kit e fazer o download e instalação do IDE e compilador, os links para os downloads encontram-se na página da unidade curricular do e-learning, bem como um tutorial de como instalar, link para o documento na última secção do documento.[2]
De seguida deverá ir ao repositório (CodeUA) e fazer o download do projeto do elevador, link para o repositório na última secção deste documento.[3] Após terminar o download do projeto deverá descompactar, abrir o MPLAB IDE e abrir o projeto. Depois apenas é necessário ligar o seu computador via USB ao compilador e este ao kit, compilar e correr o programa. Com o programa carregado no kit e todos os componentes ligados a este está pronto para começar.

## 5 Utilização do elevador

A interface entre o elevador e o utilizador é com recurso aos botões de pressão que se encontram indicados no esquema, cada um deles é relativo a um piso e um adicional serve para fazer a calibração. Além dos botões existe um LCD onde é visível em que piso se encontra ou se está a fazer calibração. Assim que estiver tudo conectado e o programa estiver carregado, o utilizador deverá começar por efetuar uma calibração ao elevador, pressionar o botão mais à direita, enquanto estiver a ser efetuada a calibração irá aparecer no LCD "Calibration", esta função tem como objetivo manter o máximo de precisão possível no elevador caso seja desligado da alimentação o micro-controlador, uma vez que o elevador é enviado para o nível mais baixo e é feito um reset às suas contagens quando este atinge o fundo.
Após a calibração o utilizador pode interagir normalmente com o elevador, quando o utilizador premir um botão, o elevador irá para o piso indicado. O primeiro botão corresponde ao piso 0, o segundo ao piso 1, o terceiro ao piso 2 e o quarto ao piso 3, tal como indicado na figura abaixo. Sempre que o elevador ficar preso em algum piso, o utilizador deverá forçar um reset, i.e., pressionar o botão calibração, que funciona com uma interrupção externa de elevada prioridade, desta forma quando for solicitado uma calibração esta será executada imediatamente, desbloqueando o elevador e podendo depois regressar à sua normal utilização.


Figura 8: Protótipo de Elevador com identificação de níveis

## Referências

[1] Repositório que contém os esquemas do PCB http://code.ua.pt/projects/sie-18-19-p4-g6/repository/revisions/master/show/Gerber_files (http://code.ua.pt/projects/sie-18-19-p4-g6/repository/revisions/master/show/Gerber_files)
[2] Tutorial de download e instalação do IDE e compilador https://elearning.ua.pt/pluginfile.php/962538/mod_resource/content/4/PIC32AppDevHowTo.pdf (https://elearning.ua.pt/pluginfile.php/962538/mod_resource/content/4/PIC32AppDevHowTo.pdf)
[3] Repositório que contém o projecto completo do elevador http://code.ua.pt/projects/sie-18-19-p4-g6/repository/revisions/master/show/Elevator_1.X (http://code.ua.pt/projects/sie-18-19-p4-g6/repository/revisions/master/show/Elevator_1.X)

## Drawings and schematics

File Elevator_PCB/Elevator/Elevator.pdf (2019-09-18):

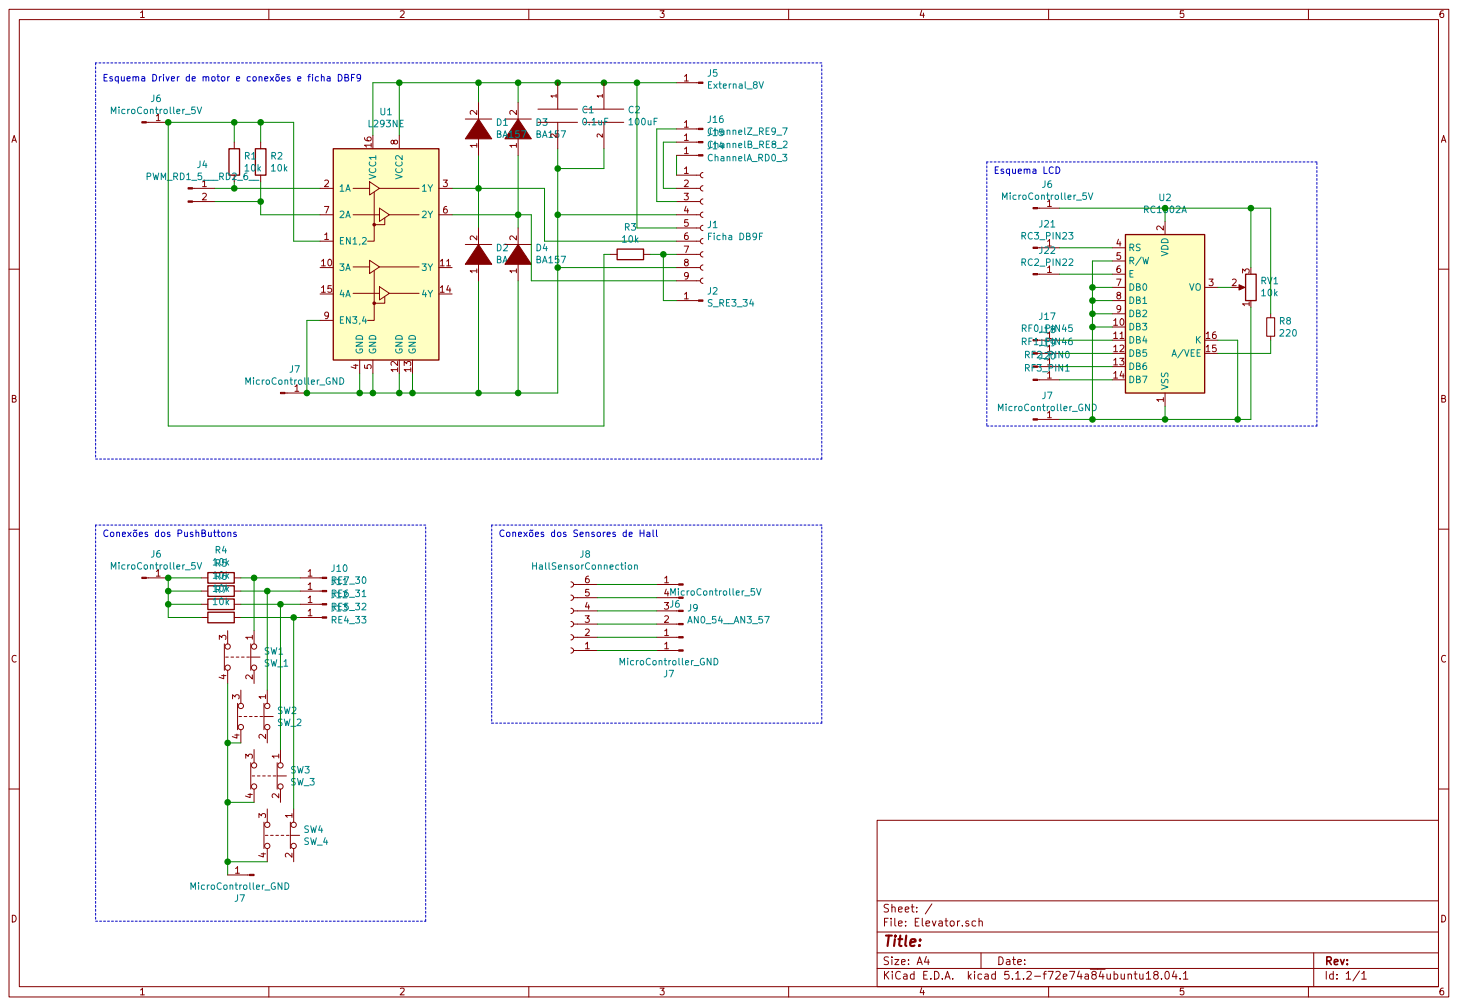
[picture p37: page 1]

Id: 1/1 Title: File: Elevator.sch Sheet: /

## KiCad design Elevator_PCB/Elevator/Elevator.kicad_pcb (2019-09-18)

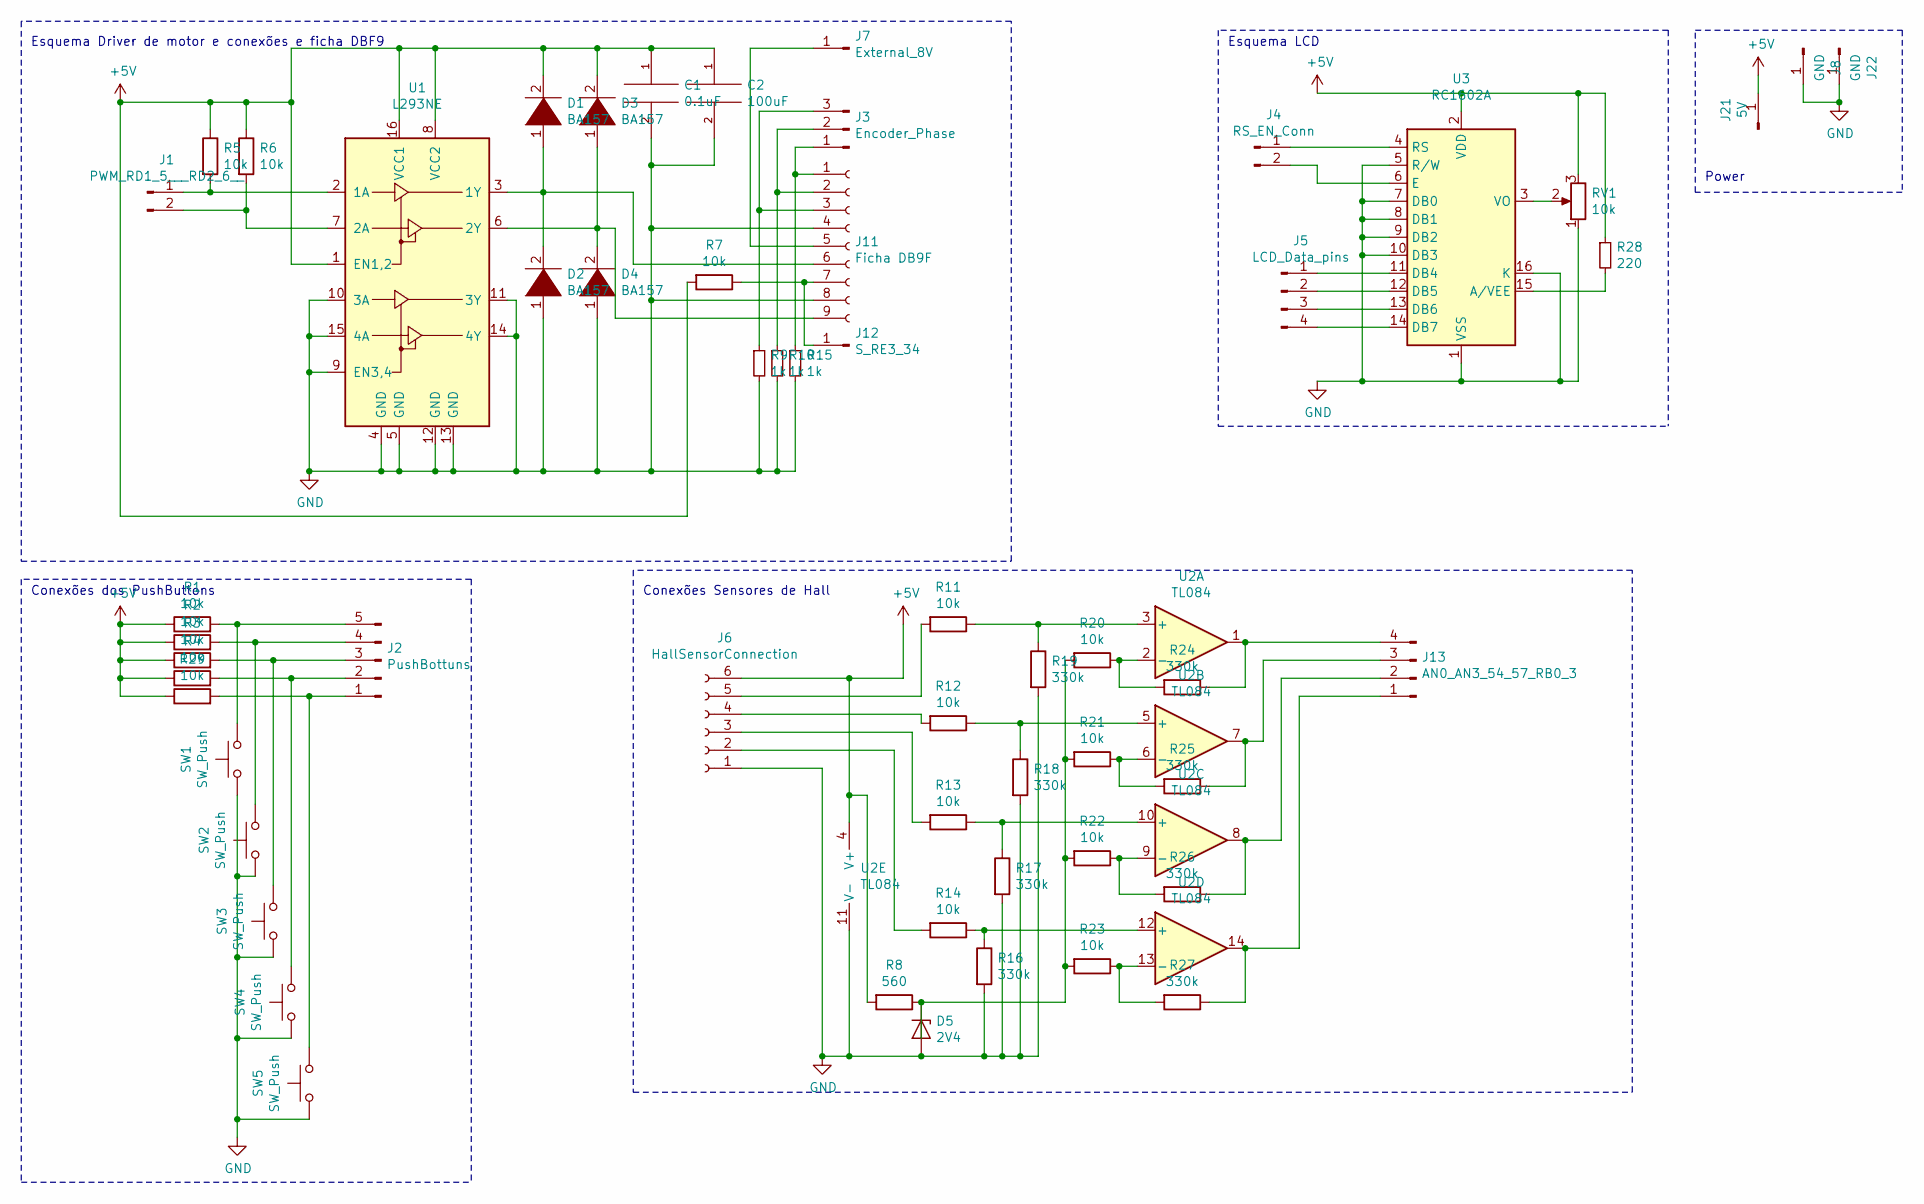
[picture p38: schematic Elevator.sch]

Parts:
C1: 0.1uF; CP_Axial_L11.0mm_D6.0mm_P18.00mm_Horizontal
C2: 100uF; CP_Axial_L11.0mm_D6.0mm_P18.00mm_Horizontal
D1, D2, D3, D4: BA157; D_DO-41_SOD81_P7.62mm_Horizontal
D5: 2V4; D_DO-35_SOD27_P7.62mm_Horizontal
J1: PWM_RD1_5___RD2_6__; PinHeader_1x02_P2.54mm_Vertical
J2: PushBottuns; PinHeader_1x05_P2.54mm_Vertical
J3: Encoder_Phase; PinHeader_1x03_P2.54mm_Vertical
J4: RS_EN_Conn; PinHeader_1x02_P2.54mm_Vertical
J5: LCD_Data_pins; PinHeader_1x04_P2.54mm_Vertical
J6: HallSensorConnection; PinHeader_1x06_P2.54mm_Vertical
J7: External_8V; PinHeader_1x01_P2.54mm_Vertical
J8, J22: GND; PinHeader_1x01_P2.54mm_Vertical
J11: Ficha DB9F; PinSocket_1x09_P2.54mm_Vertical
J12: S_RE3_34; PinHeader_1x01_P2.54mm_Vertical
J13: AN0_AN3_54_57_RB0_3; PinHeader_1x04_P2.54mm_Vertical
J21: 5V; PinHeader_1x01_P2.54mm_Vertical
R1, R2, R3, R4, R5, R6, R7, R11, R12, R13, R14, R20, R21, R22, R23, R29: 10k; R_Axial_DIN0207_L6.3mm_D2.5mm_P7.62mm_Horizontal
R8: 560; R_Axial_DIN0207_L6.3mm_D2.5mm_P7.62mm_Horizontal
R9, R10, R15: 1k; R_Axial_DIN0207_L6.3mm_D2.5mm_P7.62mm_Horizontal
R16, R17, R18, R19, R24, R25, R26, R27: 330k; R_Axial_DIN0207_L6.3mm_D2.5mm_P7.62mm_Horizontal
R28: 220; R_Axial_DIN0207_L6.3mm_D2.5mm_P7.62mm_Horizontal
RV1: 10k; Potentiometer_ACP_CA9-H5_Horizontal
SW1, SW2, SW3, SW4, SW5: SW_Push; SW_PUSH_6mm_H5mm
U1: L293NE; DIP-16_W7.62mm
U2: TL084; DIP-14_W7.62mm_Socket_LongPads
U3: RC1602A; PinSocket_1x17_P2.54mm_Vertical

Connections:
+5V: C1.1, C2.1, D1.2 (A), D3.2 (A), J6.6, J21.1, R1.1, R2.1, R3.1, R4.1, R5.1, R6.1, R7.2, R8.2, R28.1, R29.1, RV1.3, U1.1 (EN1,2), U1.8 (VCC2), U1.16 (VCC1), U2.4 (V+), U3.2 (VDD)
GND: C1.2, C2.2, D2.1 (K), D4.1 (K), D5.2 (A), J6.1, J8.1, J11.4, J11.8, J22.1, R9.2, R10.2, R15.2, R16.2, R17.2, R18.2, R19.2, RV1.1, SW1.1, SW2.1, SW3.1, SW4.1, SW5.1, U1.4 (GND), U1.5 (GND), U1.9 (EN3,4), U1.10 (3A), U1.11 (3Y), U1.12 (GND), U1.13 (GND), U1.14 (4Y), U1.15 (4A), U2.11 (V-), U3.1 (VSS), U3.5 (R/W), U3.7 (DB0), U3.8 (DB1), U3.9 (DB2), U3.10 (DB3), U3.16 (K)
unnamed: D1.1 (K), D2.2 (A), J11.6, U1.3 (1Y)
unnamed: D3.1 (K), D4.2 (A), J11.9, U1.6 (2Y)
unnamed: D5.1 (K), R8.1, R20.2, R21.2, R22.2, R23.2
unnamed: J1.1, R5.2, U1.2 (1A)
unnamed: J1.2, R6.2, U1.7 (2A)
unnamed: J2.1, R29.2, SW5.2
unnamed: J2.2, R4.2, SW4.2
unnamed: J2.3, R3.2, SW3.2
unnamed: J2.4, R2.2, SW2.2
unnamed: J2.5, R1.2, SW1.2
unnamed: J4.1, U3.4 (RS)
unnamed: J4.2, U3.6 (E)
unnamed: J5.1, U3.11 (DB4)
unnamed: J5.2, U3.12 (DB5)
unnamed: J5.3, U3.13 (DB6)
unnamed: J5.4, U3.14 (DB7)
unnamed: J6.2, R14.2
unnamed: J6.3, R13.2
unnamed: J6.4, R12.2
unnamed: J6.5, R11.2
unnamed: J3.1, J11.1, R15.1
unnamed: J3.2, J11.2, R10.1
unnamed: J3.3, J11.3, R9.1
unnamed: J7.1, J11.5
unnamed: J11.7, J12.1, R7.1
unnamed: J13.1, R27.1, U2.14
unnamed: J13.2, R26.1, U2.8
unnamed: J13.3, R25.1, U2.7
unnamed: J13.4, R24.1, U2.1
unnamed: R11.1, R19.1, U2.3 (+)
unnamed: R12.1, R18.1, U2.5 (+)
unnamed: R13.1, R17.1, U2.10 (+)
unnamed: R14.1, R16.1, U2.12 (+)
unnamed: R20.1, R24.2, U2.2 (-)
unnamed: R21.1, R25.2, U2.6 (-)
unnamed: R22.1, R26.2, U2.9 (-)
unnamed: R23.1, R27.2, U2.13 (-)
unnamed: R28.2, U3.15 (A/VEE)
unnamed: RV1.2, U3.3 (VO)

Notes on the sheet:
Esquema Driver de motor e conexões e ficha DBF9
Conexões dos PushButtons
Esquema LCD
Conexões Sensores de Hall
Power

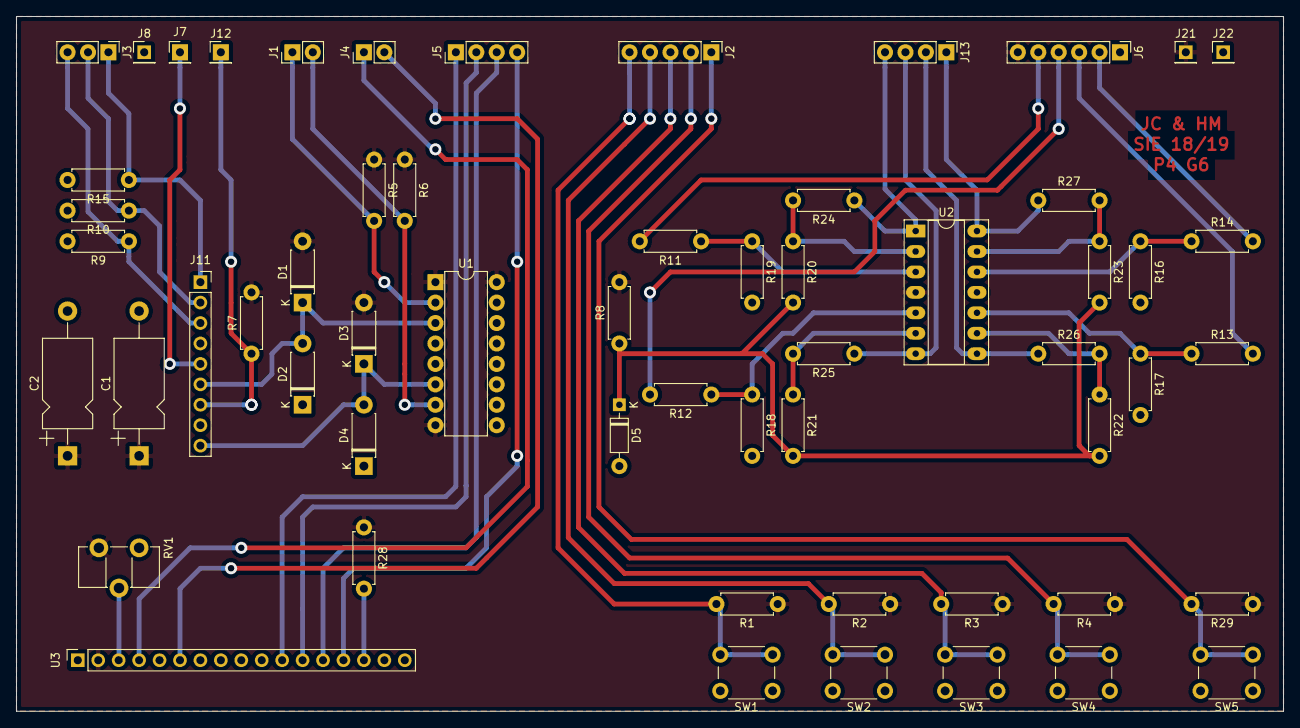
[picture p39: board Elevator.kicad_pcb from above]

Board: 2 copper layers, 157.5 x 86.4 mm, 58 parts (0 on the bottom side), 41 nets.

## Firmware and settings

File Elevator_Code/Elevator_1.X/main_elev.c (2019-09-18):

/* 
 * File:   main_elev.c
 * Author:  João Cruz       - 76517
 *          Henrique Martins- 76674    
 */
#include "config_bits.h"
#include <stdio.h>
#include <stdlib.h>
#include <xc.h>
#include <sys/attribs.h>
#include <math.h>

#include "pwm.h"              //- Funciona
#include "crystal_display.h"  //- Nao funciona
#include "encoder.h"          //- Nao testada
#include "buttons.h"          //- Testada
#include "adc.h"
#include "uart.h"
#define br 9600
#define pbclk 40000000L
/*
 * 
 */

volatile uint8_t level = 0;
volatile uint32_t setpoint = 0;

#define DP 100
const uint16_t Kp = 20, Ti = 2;
const uint32_t mid_point = 745;
int32_t e[2]={0 , 0} ;
int32_t u[2]={ 0 , 0};
uint16_t f = 10;
uint32_t s0, s1;
uint32_t pwm1, pwm2;
uint32_t err;
uint32_t buff;


void init(void);
void SetExternalInt3(void);
void PIInit(void);
void PI_Controller(void);
void Init_Timer1_Interrupt();
void Init_Timer5_Interrupt();

int main(int argc, char** argv){
    
    InitialiseDisplay();
    uint8_t p = 5;
    UpdateL1(p);
    //Init_UART();
    //__XC_UART =1;
    
    init();      
           
    while(1)
    {        
        
    }
    return (EXIT_SUCCESS);
}
void init(void)
{

    InitButtons();
    SetTimer();
    TRISDbits.TRISD1 = 0;   //define as output OC2 - pin 5
    TRISDbits.TRISD2 = 0;   //define as output OC3 - pin 6
    
    TRISEbits.TRISE2 = 0;
    
    PORTEbits.RE2 = 0;
    SetEncoderPorts();  
    
    initADCTimer();
    initADC();
    
           

    
    SetExternalInt3();      //Calibration
                          
    SetExternalInt0();   //pino 3
    SetExternalInt1();  // pino 2
    SetExternalInt2();  // pino 7
    //PI 
    PIInit();        
    
    Init_Timer1_Interrupt();        //Leitura dos botões e setpoint       
    Init_Timer5_Interrupt();        //Controlador PI
    
    INTCONSET = _INTCON_MVEC_MASK;
    __builtin_enable_interrupts();
}

void __ISR(_EXTERNAL_3_VECTOR, IPL5SRS) da (void){     
        UpdateL3();
        setPWM1(100);
        setPWM2(0);        
        while(BottomSwitch()==0);                
        setPWM1(0);
        setPWM2(0);
        IFS0bits.INT3IF = 0; // Reset interrupt flag           
        delay(3000);
        
        ResetPos(); //reset do counter da posição
        setpoint = 0;
        e[1]=0;
        u[1]=0;
        e[0]=0;
        u[0]=0;
        
    
}

void SetExternalInt3(void)
{
    TRISAbits.TRISA14 = 1; // Set pin as input PushBotton3 - pin 21 INT3
    IEC0bits.INT3IE = 0; // Disable Int0 interrupts
    IFS0bits.INT3IF = 0; // Reset int flag
    INTCONbits.INT3EP = 0; // Generate interrupts on {rising edge-1 falling edge - 0}
    IPC3bits.INT3IP = 2; // Set interrupt priority (1..7) *** Set equal to ilpx above
    IEC0bits.INT3IE = 1; // Enable Int0 interrupts     
}



void Init_Timer1_Interrupt()
{
    //Fa para leitura dos botões
    
    //for position
    T1CONbits.ON = 0; //stop timer
    IFS0bits.T1IF=0; //reset flag
    IPC1bits.T1IP=2; //priority
    IEC0bits.T1IE =1; //enable interrupts
    T1CONbits.TCKPS =3; //prescaler 256
    PR1=15625; //fout=10hz                      DEVIA SER 100 HZ
    TMR1=0;
    T1CONbits.ON=1; //start
    T1CONbits.TON = 1;    
}

void __ISR( _TIMER_1_VECTOR, IPL5SRS) timer1_int(void)
{
   // Rotina da leitura dos botões 
    
    if(PushButton0() == 1){
        level = 0;
        setpoint = 0 ; 
        UpdateL2(level);        
    }
    if(PushButton1() == 1){
        level = 1;        
        setpoint = 3090 ;
        UpdateL2(level);        
    }
    if(PushButton2() == 1){
        level = 2;        
        setpoint = 5997 ;  
        UpdateL2(level);
    }
    if(PushButton3() == 1){
        level = 3;        
        setpoint = 9063;  
        UpdateL2(level);
    }           
    IFS0bits.T1IF = 0;
}

void Init_Timer5_Interrupt()
{
    //impoe frequencia de amostragem ao controlador PI
    
    T5CONbits.ON = 0; //stop timer
    IFS0bits.T5IF=0; //reset flag
    IPC5bits.T5IP=2; //priority
    IEC0bits.T5IE =1; //enable interrupts
    T5CONbits.TCKPS =7; //prescaler 256
    PR5=311; //fout=100Hz
    TMR5=0;
    T5CONbits.ON=1; //start
}

void __ISR( _TIMER_5_VECTOR, IPL5SRS) timer5_int(void){    
    PI_Controller();        
    IFS0bits.T5IF = 0;
}

void PIInit(void)
{
    s0=Kp*(DP+DP/(Ti*f))/DP;
    s1 = -Kp;
}

void PI_Controller(void)
{        
    if(setpoint == 0)
    {
        buff = readADC0();
    }
    if(setpoint == 3090)
    {
        buff = readADC1();
    }
    if(setpoint == 5997)
    {
        buff = readADC2();
    }
    if(setpoint == 9063)
    {
        buff = readADC3();
    }
    
    err = (buff-mid_point);        
    e[1]=e[0];
    u[1]=u[0];
    e[0]=setpoint-GetPos();
    u[0]=u[1]+(s0*e[0]+s1*e[1])/DP;
    if(e[0]>0)
    {
        pwm1 = u[0];
        pwm2 = 0;
    }if(e[0]<0)
    {
        pwm1 = 0;
        pwm2 = u[0];
    }
    setPWM1(pwm2);
    setPWM2(pwm1);
    
    
    
    e[0]=(setpoint-GetPos()); //error signal
    u[0]= fabs(e[0]);
}
 
    

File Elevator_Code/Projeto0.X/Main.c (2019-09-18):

/* 
 * File:   main.c
 * Author: João André, Henrique Martins
 *
 * Created on 5 de Março de 2019, 17:08
 */
#include "../../ExemploCodigo/CKCommon/ConfigBits/config_bits.h" // NOTE!! Must precede project file includes
#include <xc.h>
#include <stdio.h>
#include <stdlib.h>
#include <stdint.h>
#include <stdbool.h>
/*
 *
 */
#define SYSCLK  80000000L // System clock frequency, in Hz
#define PBCLOCK 40000000L // Peripheral Bus Clock frequency, in Hz
/*
 * 
 */
#define fpwm 2000 //sampling frequency
#define NUMBER_OF_PRESCALERS (sizeof(prescalers)/sizeof(prescalers[0]))
#define max_pr2 65535
#define nbits 256   //2^8=256

#define flagTimer (IFS0bits.T3IF)
#define flagADC (IFS1bits.AD1IF)
/*
 *
 */
uint8_t set_timer(uint32_t freq);
void init(void);
void initADC(void);
void init_pwm(uint8_t duty_cycle);
/*Main code*/
int main(int argc, char** argv) {
    int fa;
    int fa2 = 400;
    fa=nbits*fpwm;
    set_timer(fa2);
    init();
    int res=0;
    int max=0;
    int min=100;
    int mean;
    initADC();
    while(1)
    {
        
        // Read ADC 

        AD1CON1bits.ASAM = 1; // Start conversion

        if (flagTimer == 1){
            flagTimer = 0;
            AD1CON1bits.ASAM = 1; // Start conversion
        }
        if (flagADC == 1){
            res = (ADC1BUF0*100)/1024;  // Convertion of ADC buffer from 0-100 
            flagADC = 0;
            
        }
        
            init_pwm(res);             //Start PWN signal
        
#if 0
        while(IFS0bits.T2IF==0);
        IFS0bits.T2IF=0;
        if(flag==1)
        {
            PORTDbits.RD1= 0;
            flag=0;
        }
        else
        {
            PORTDbits.RD1=1;
            flag=1;
        }
#endif
    }
    return (EXIT_SUCCESS);
}
/*Set ports and Timers */
void init(void)
{
    TRISDbits.TRISD0 = 0;
    PORTDbits.RD0= 1;  
    
    // Set timer of PWN 2k Hz
    T2CONbits.ON = 0; // Stop timer
    IFS0bits.T2IF=0; // Reset interrupt flag    
    T2CONbits.TCKPS = 0; //Select pre-scaler
    T2CONbits.T32 = 0; // 16 bit timer operation
    PR2=20000; // Compute PR value
    TMR2=0;
    
    // Set timer of ADC 400 Hz
    T3CONbits.ON = 0; // Stop timer
    IFS0bits.T3IF=0; // Reset interrupt flag    
    T3CONbits.TCKPS = 1; //Select pre-scaler
    
    //PR3=50000; // Compute PR value
    //TMR3=0;
    
    T3CONbits.TON=1; // Start the timer
    T3CONbits.ON=1; // Start the timer
}

#if 1
uint8_t set_timer(uint32_t freq) 
{
    /*Value for counter prescaler*/
    uint16_t prescalers[] ={1, 2, 4, 8, 16, 32, 64, 256};
    /*defining variables*/
    uint32_t div;
    uint8_t i=NUMBER_OF_PRESCALERS-1;
    /*Check if sampling frequency is equal to zero, if its the case, stops the timer*/
    if(freq==0)
    {
       return 0;
    }
    div=PBCLOCK/freq;
    /*Try to find the best prescaler value*/
    while(((div%prescalers[i])!=0) && (div/prescalers[i]>max_pr2))
    {
        i--;
        /*If none of the prescaler fits, it will return no valid value*/
        if(i<0)
            return -1;   
    }

    PR3=div/prescalers[1];
    TMR3=0;
    return 0;
}
#endif 
#if 1
void initADC(void){
    AD1CON1bits.SSRC = 7; // Internal counter ends sampling and starts conversion
    AD1CON1bits.CLRASAM = 1; //Stop conversion when 1st A/D converter interrupt is generated and clears ASAM bit automatically
    AD1CON1bits.FORM = 0; // Integer 16 bit output format
    AD1CON2bits.VCFG = 0; // VR+=AVdd; VR-=AVss
    AD1CON2bits.SMPI = 0; // Number (+1) of consecutive conversions, stored in ADC1BUF0...ADCBUF{SMPI}
    AD1CON3bits.ADRC = 1; // ADC uses internal RC clock
    AD1CON3bits.SAMC = 16; // Sample time is 16TAD ( TAD = 100ns)
    // Set AN0 as input
    AD1CHSbits.CH0SA = 0; // Select AN0 as input for A/D converter
    TRISBbits.TRISB0 = 1; // Set AN0 to input mode
    AD1PCFGbits.PCFG0 = 0; // Set AN0 to analog mode
    // Enable ADC
    AD1CON1bits.ON = 1; // Enable A/D module (This must be the ***last instruction of configuration phase***)
    
    T3CONbits.TON=1; // Start the timer
}
#endif
void init_pwm(uint8_t duty_cycle)
{
    if(duty_cycle<0)
        duty_cycle=0;
    if(duty_cycle>100)
        duty_cycle=100;
    //duty_cycle = 100-duty_cycle;
    
    // Set OC1
    OC1CONbits.OCM = 6; // OCM = 0b110 : OC1 in PWM mode,
    OC1CONbits.OCTSEL=0; // Timer 2 is clock source of OCM
    OC1RS=((PR2+1)*duty_cycle)/100; // Compute OC1xRS value
    OC1CONbits.ON=1;     // Enable OC1

    // Start PWM generation
    T2CONbits.TON=1; // Start the timer
}
